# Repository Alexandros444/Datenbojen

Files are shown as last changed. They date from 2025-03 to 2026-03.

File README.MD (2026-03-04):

# Datenbojen
In diesem Projekt wird die Umsetzung einer autonomen Datenerfassungsplattform dokumentiert.

## Bachelorarbeit
Genaueres zu dem Projekt kann in der Bachelorarbeit von Alexander Mohr nachgelesen werden.
[Bachelorarbeit](docs/Datenbojen_Bachelor_Arbeit.pdf)

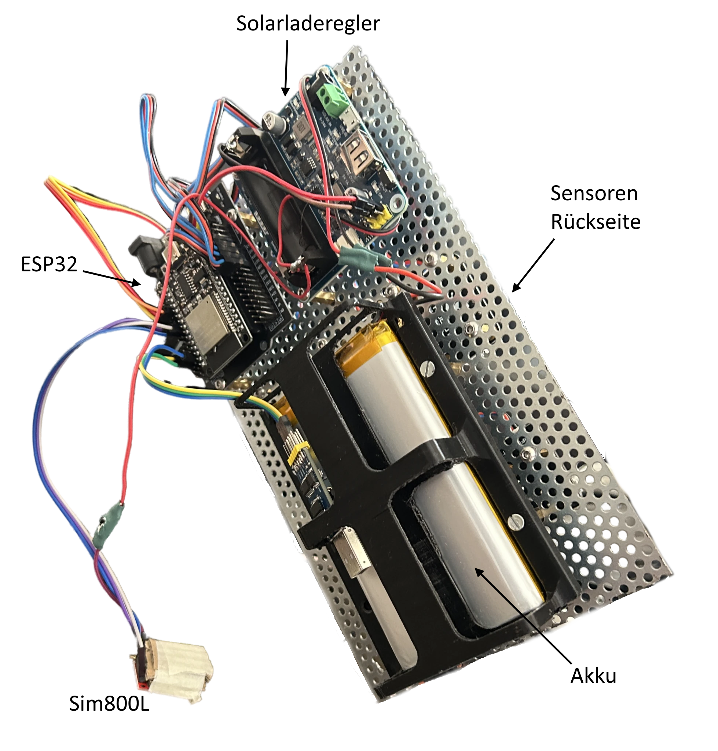
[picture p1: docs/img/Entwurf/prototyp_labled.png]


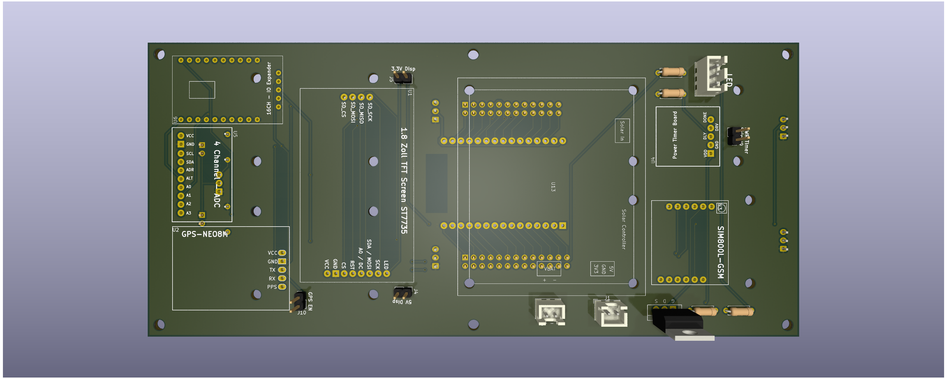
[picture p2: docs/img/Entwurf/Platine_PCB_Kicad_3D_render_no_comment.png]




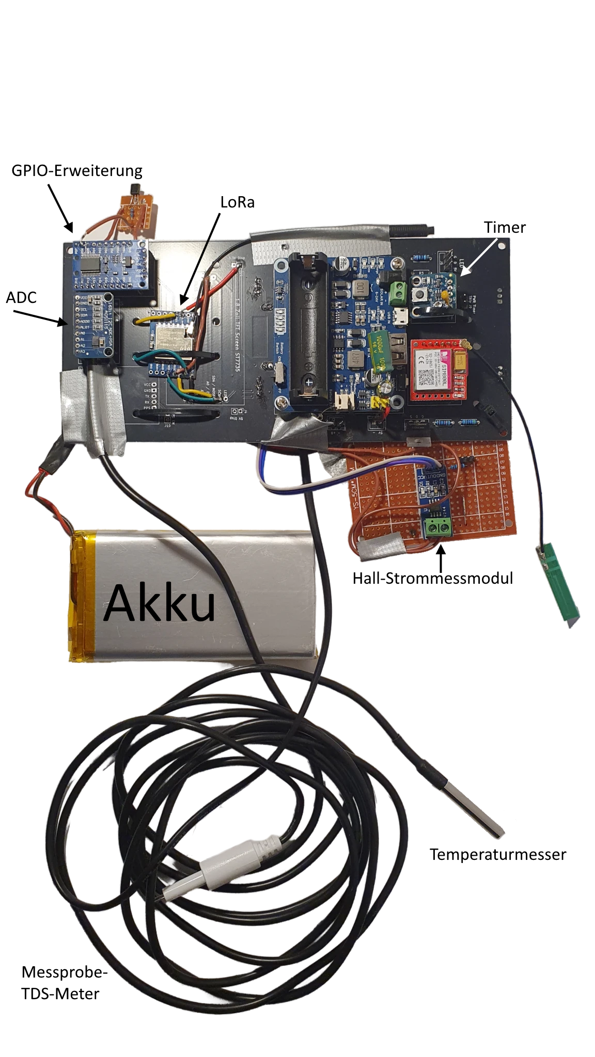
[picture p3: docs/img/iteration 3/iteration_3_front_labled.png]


## Ausstellung
Ein Prototyp des Projekts wurde im Berliner Humboldt Forum ausgestellt.
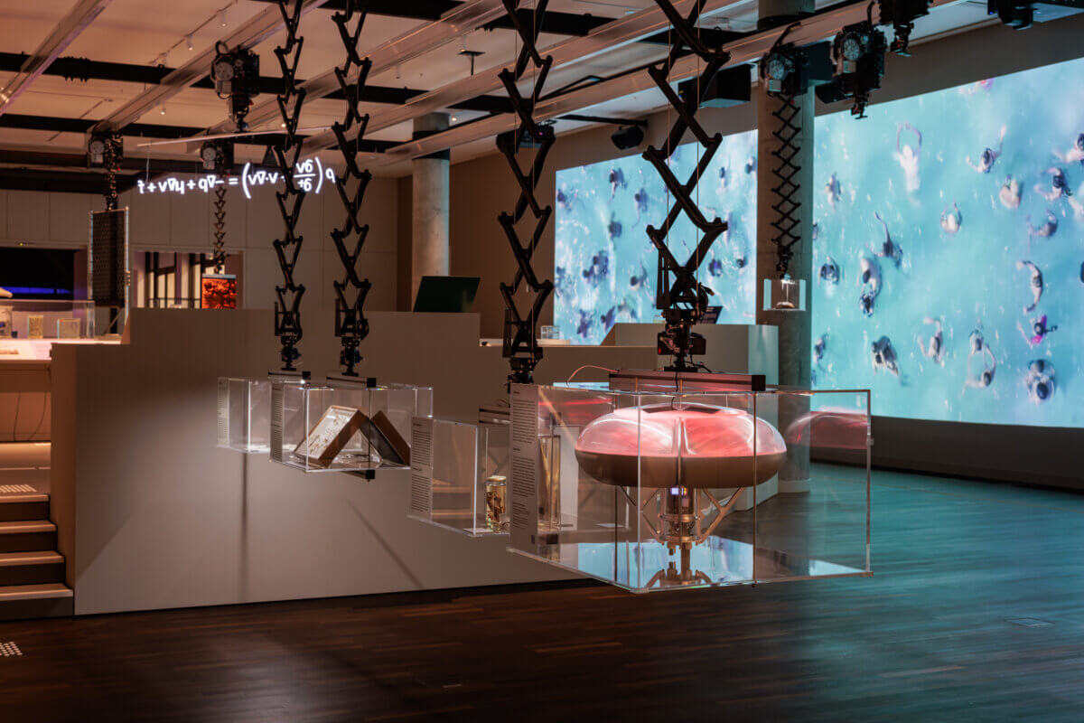
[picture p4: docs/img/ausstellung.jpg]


## Rückfragen
- Email an a.mohr@campus.tu-berlin.de

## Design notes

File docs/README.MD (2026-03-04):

## Bachelorarbeit
[Datenbojen](Datenbojen_Bachelor_Arbeit.pdf)

## Sim-800L
- Dokumentation in [Sim800L_Manual](SIM800%20Series%20AT%20Command%20Manual%20V1.10-1.pdf)
- Kurzfassung in [Docx](AT_Commands.docx)

## Systementwurf
- Flowcharts zur Systemfunktion

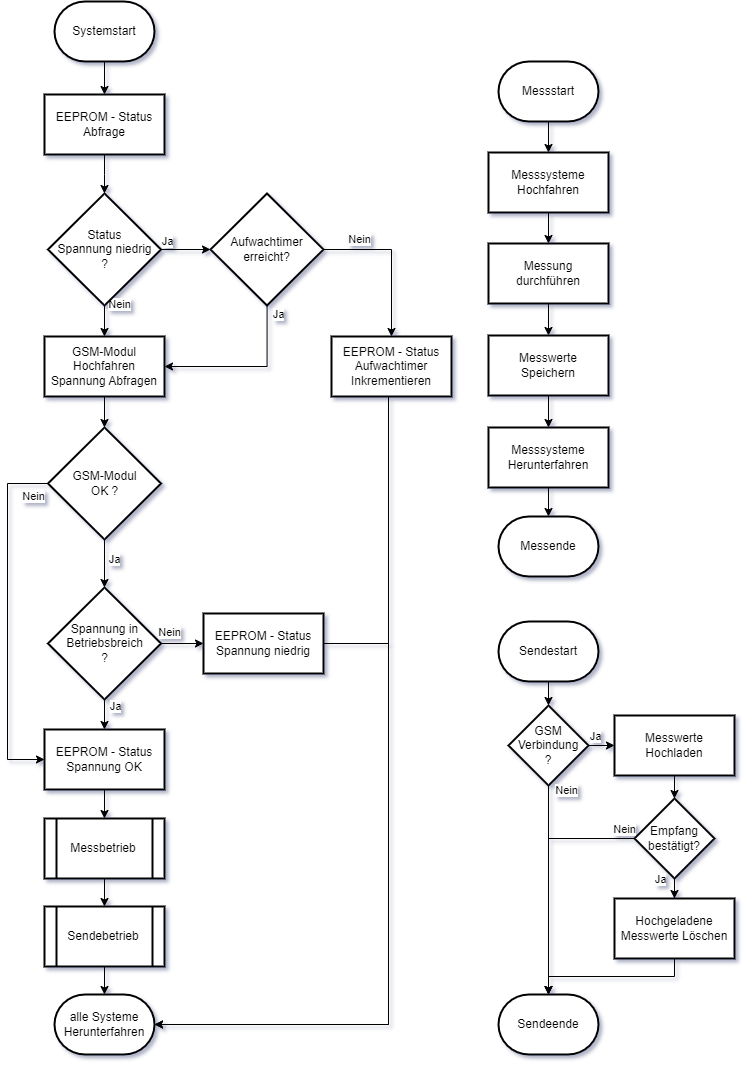
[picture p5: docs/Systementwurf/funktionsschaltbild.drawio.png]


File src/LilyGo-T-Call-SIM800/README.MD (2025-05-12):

<h1 align = "center">🌟LilyGo T-Call SIM800 Series🌟</h1>

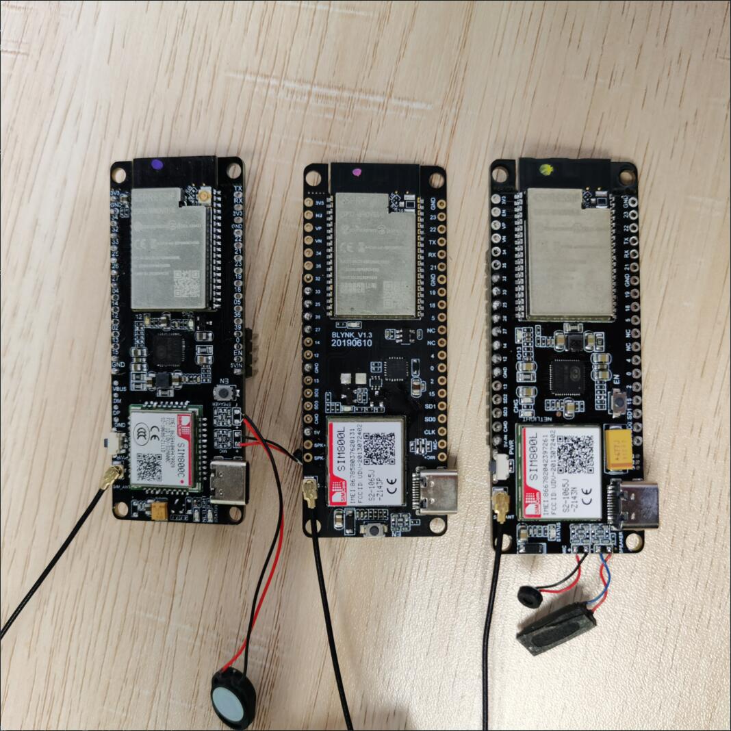
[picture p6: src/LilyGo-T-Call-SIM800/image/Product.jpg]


<h2 align = "left">Product 📷:</h2>

| Examples | Product  Link | Schematic |
| :---: | :---: | :---: |
| [SIM800L IP5306 20200811](./doc/SIM800L_IP5306.MD) | [Product link](https://lilygo.cc/products/t-call-v1-4?variant=42868250869941) | [Schematic](./schematic/LilyGo-SIM800L-IP5306-20200811.pdf) |

## Datasheet

- [SIM800 AT Command](./datasheet/sim800_series_at_command_manual_v1.01.pdf)
- [SIM800 Hardware Design](./datasheet/SIM800_Hardware%20Design_V1.08.pdf)
- [AXP192](http://www.x-powers.com/en.php/Info/product_detail/article_id/29)
- [IP5306](./datasheet/IP5306%20REG%20V1.4.pdf)

## PlatformIO Quick Start

1. Install [Visual Studio Code](https://code.visualstudio.com/) and [Python](https://www.python.org/)
2. Search for the `PlatformIO` plugin in the `VisualStudioCode` extension and install it.
3. After the installation is complete, you need to restart `VisualStudioCode`
4. After restarting `VisualStudioCode`, select `File` in the upper left corner of `VisualStudioCode` -> `Open Folder` -> select the `LilyGo-T-Call-SIM800` directory
5. Wait for the installation of third-party dependent libraries to complete
6. Click on the `platformio.ini` file, and in the `platformio` column
7. Uncomment one of the lines `src_dir = xxxx` to make sure only one line works
8. Click the (✔) symbol in the lower left corner to compile
9. Connect the board to the computer USB
10. Click (→) to upload firmware
11. Click (plug symbol) to monitor serial output
12. If it cannot be written, or the USB device keeps flashing, please check the **FAQ** below

## Arduino IDE Manual installation

1. Install [Arduino IDE](https://www.arduino.cc/en/software)
2. Install [Arduino ESP32 V2.0.5 or later or latest](https://docs.espressif.com/projects/arduino-esp32/en/latest/)
3. Download `LilyGo-T-Call-SIM800` , move to Arduino library folder (e.g. C:\Users\YourName\Documents\Arduino\libraries)
4. Copy all folders in [lib folder](./lib/) to Arduino library folder (e.g. C:\Users\YourName\Documents\Arduino\libraries)
5. Open ArduinoIDE ,`Tools` , Make your selection according to the table below
   | Arduino IDE Setting                  | Value                             |
   | ------------------------------------ | --------------------------------- |
   | Board                                | **ESP32 Dev Module**            |
   | Port                                 | Your port                         |
   | USB CDC On Boot                      | Enable                            |
   | CPU Frequency                        | 240MHz (WiFi/BT)                      |
   | Core Debug Level                     | None                              |
   | Erase All Flash Before Sketch Upload | Disable                           |
   | Events Run On                        | Core1                             |
   | Flash Mode                           | QIO 80MHZ                         |
   | Flash Size                           | **4MB (32Mb)**                   |
   | Arduino Runs On                      | Core1                             |
   | Partition Scheme                     | **Default 4MB with spiffs (1.2MB APP/1.5MB SPIFFS)** |
   | PSRAM                                | **QSPI PSRAM**                     |
   | Upload Mode                          | **UART0/Hardware CDC**            |
   | Upload Speed                         | 921600                            |

   - The options in bold are required, others are selected according to actual conditions.

6. `File` -> `Examples` -> `LilyGo-T-Call-SIM800` -> `Arduino Examples`
7. Select `Port`
8. Click `upload` , Wait for compilation and writing to complete

## FAQ

### 1. If you are unable to download, please try the following steps, if it still does not work, please contact customer service

1. Open the serial monitor
2. Short IO0 to GND
3. Press the RESET button on the board, if the serial port communication is normal, then you should see

    ```bash
    ets Jun 8 2016 00:22:57

    rst:0x1 (POWERON_RESET),boot:0x3 (DOWNLOAD_BOOT(UART0/UART1/SDIO_REI_REO_V2))
    waiting for download
    ```

4. If you can see the above message, it means that the communication is normal, then all you need is to let it enter the waiting download mode, then you can click upload, usually it can solve the problem of not being able to download automatically

### 2. About the 5V power pin description on the board

   - For IP5306 power supply, the 5V power pin connected to the USB board is the output, and the voltage is boosted by IP5306 power supply chip.  According to the manual, its maximum output current is 2.4a.  Do not connect USB, can 5V input.
   - When using AXP192 power supply, the 5V power pin on the board is the input, and it is connected with USB 5V+. There is no other power output on the board except for the 3.3V output.

### 3. Didn’t connect to the Internet for a long time, or just turned off suddenly?

   - It may be due to insufficient USB power supply current, please connect a lithium battery to the board, then plug in the USB and test again.

### 4. Why doesn’t the board turn on when the lithium battery is connected?

   - If you use the **IP5306** version and use a lithium battery to supply power, you must press the reset button to turn on the board. 
   - If you use the **AXP192** power management chip, you need to press and hold the PWR button for 2 seconds to turn on the power supply. By default, the AXP192 will be powered on when the battery is inserted. 

### 5. About SIM800X built-in firmware update

   - SIM800 built-in firmware update tool Because SIMCOM has not adapted and updated the new system for a long time, it is not necessarily available to upgrade the built-in firmware tool. Most users are stuck waiting for download. Please be informed
   - [How to update firmware](doc/How%20to%20update%20firmware.md)

### 6. LED indicators

- Blue LED, controlled by GPIO13
- Red LED, network status light

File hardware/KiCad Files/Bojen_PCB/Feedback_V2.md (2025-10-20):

## IO Expander
- [x] Silkscreen missing
- [x] Holes to small
- Weitere Pins zugänglich machen

## Sim Module
- [x] Silkscreen missing
- [ ] Mosfet DOES NOT WORK, Wenn ESP aus, wird gpio auf GND gezogen,  ~1.1V gemessen Spannungsteiler innenwiderstand berechnen? Auf Nicht inv. wechseln
- RESET PIN wird gebraucht

## TMP Sensor
- [x] Beschriftung Falsch "- + D" -> "- D +"

## GSM Module
- [x] Mehr Pufferkondensatoren
    - 100u, 10u
- [x] PWR Mosfet Skip
- [x] RST Pin auf GPIO für Hard Reset

## Power
- [x] Puffer Kondensatoren
    - 100u, 10u

## Kosten
- JST - XH - 5€
- Pin Headers - 2€
- DS18B20

# ESP
- [x] GPIO Label Silkscreen TODO / Label Pin Header
- [x] USB-C kann man nicht einstecken wenn Sensoren verbaut. ggf. (Sensoren Tiefer legen) oder esp mehr nach unten
- [o] USB verbindung rausführen, aber USB - TTL benötigt (not worth it)

# Mount Holes
- Mehr Clearence
- [x] Besonders bei den ESP-GPIO Pins zu dem mount vom Waveshare solar board

# Solar Modul
- Power reroute backup, Battery voltage for development

# Sensoren
- [x] Sensoren Distanz zu Board anschlüssen sind zu kurz für Steckverbindungen
- ADC Pins beschriften Bei Sensoren A0-A3

# Board
- Alle Pins rausbringen (oben Vcc anschlüsse etc.)
- [x] Alle GPIO Pin header für extension board
- GPIO Default connected pins (everywhere solder work minimizing)

# LED
- Braucht kein Widerstand für Data weil, ESP 3.3V

# Timer
- [x] Buffer Capacitor

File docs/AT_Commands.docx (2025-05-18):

Network Registration:

AT+CREG

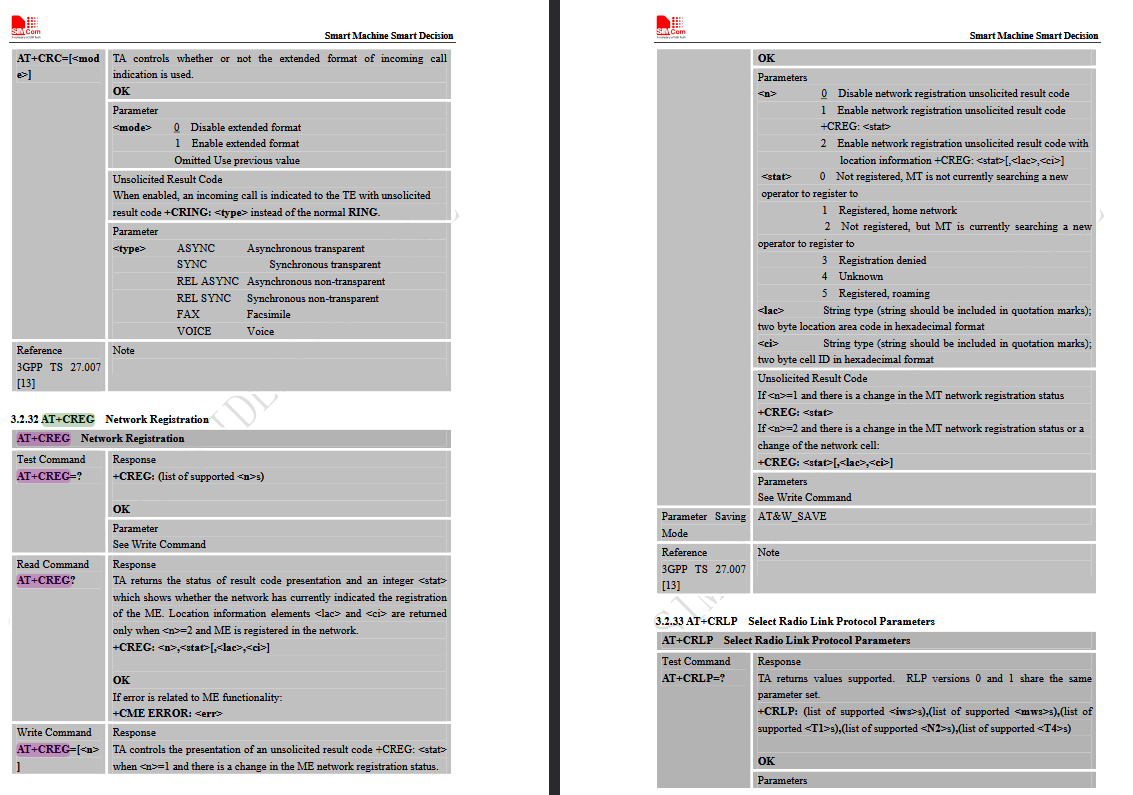
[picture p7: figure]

AT+CGREG

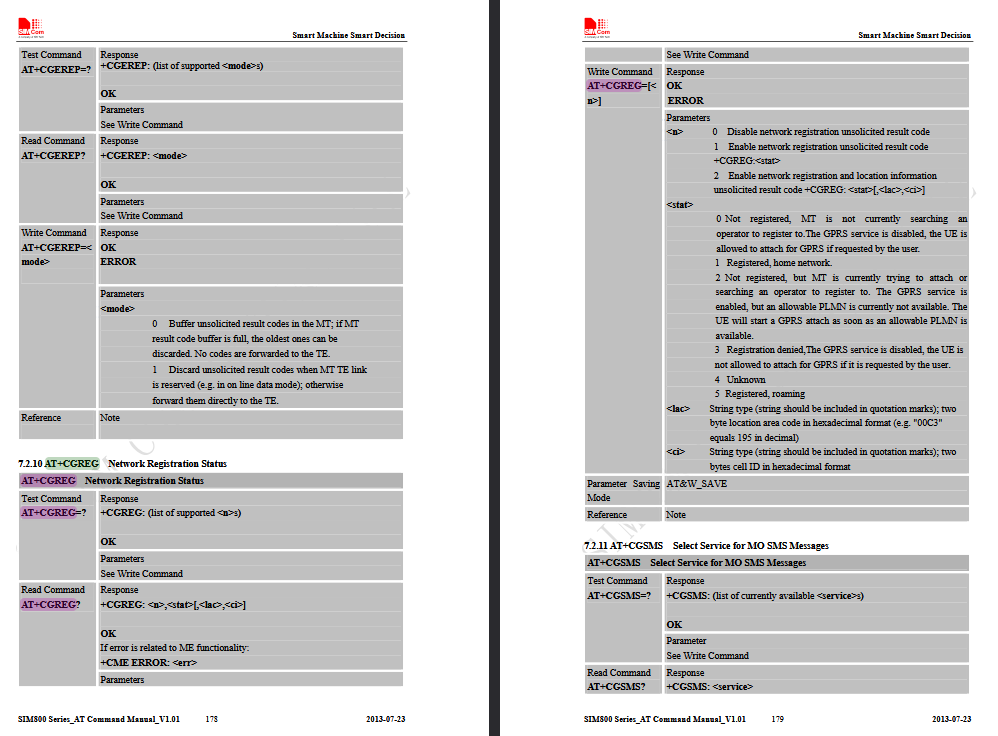
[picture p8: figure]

Settings Bearer IP Application

AT+SAPBR

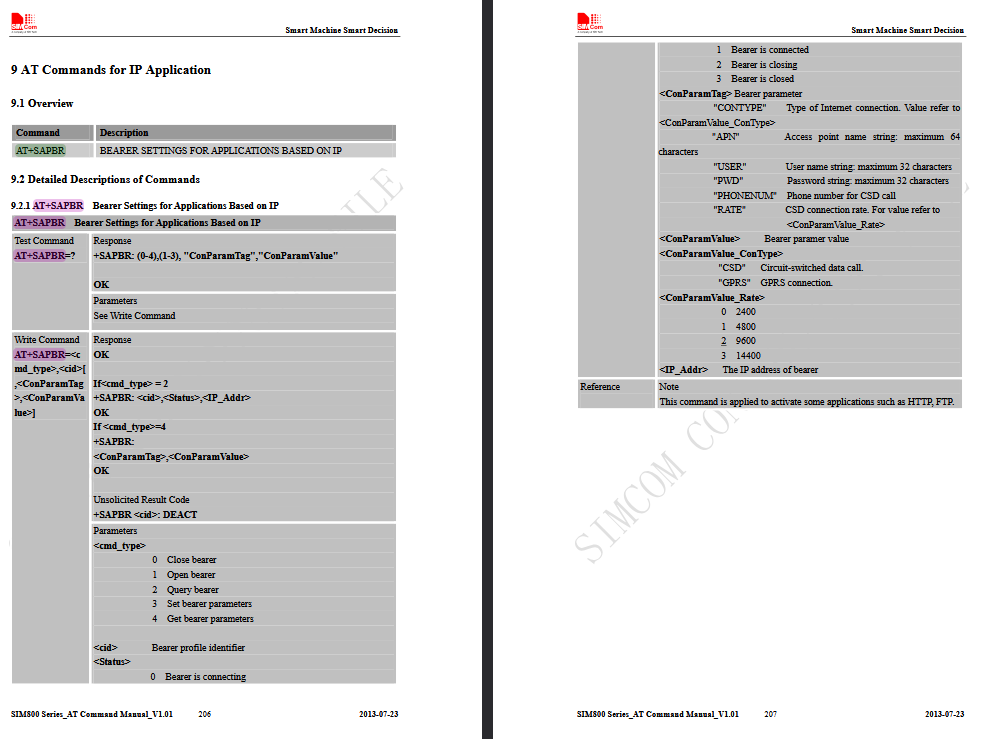
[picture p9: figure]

AT+HTTPINIT

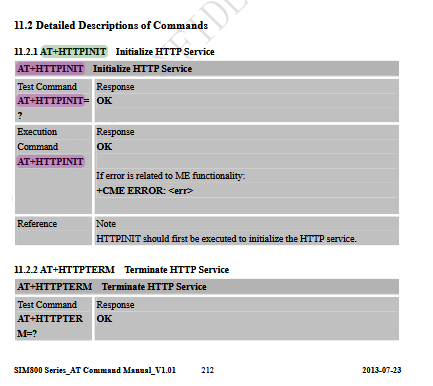
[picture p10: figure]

AT+HTTPPARA

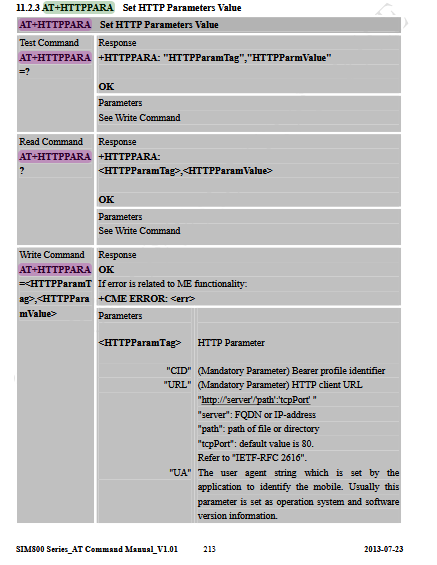
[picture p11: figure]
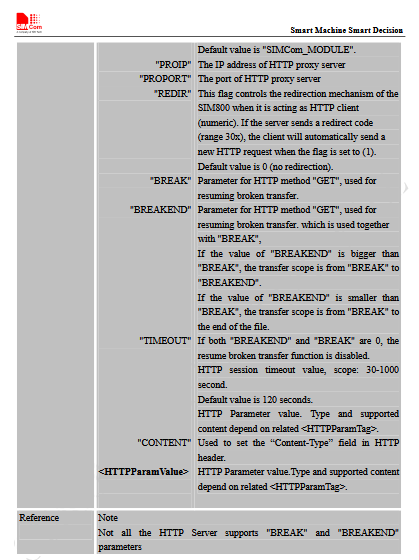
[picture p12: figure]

AT+HTTPDATA

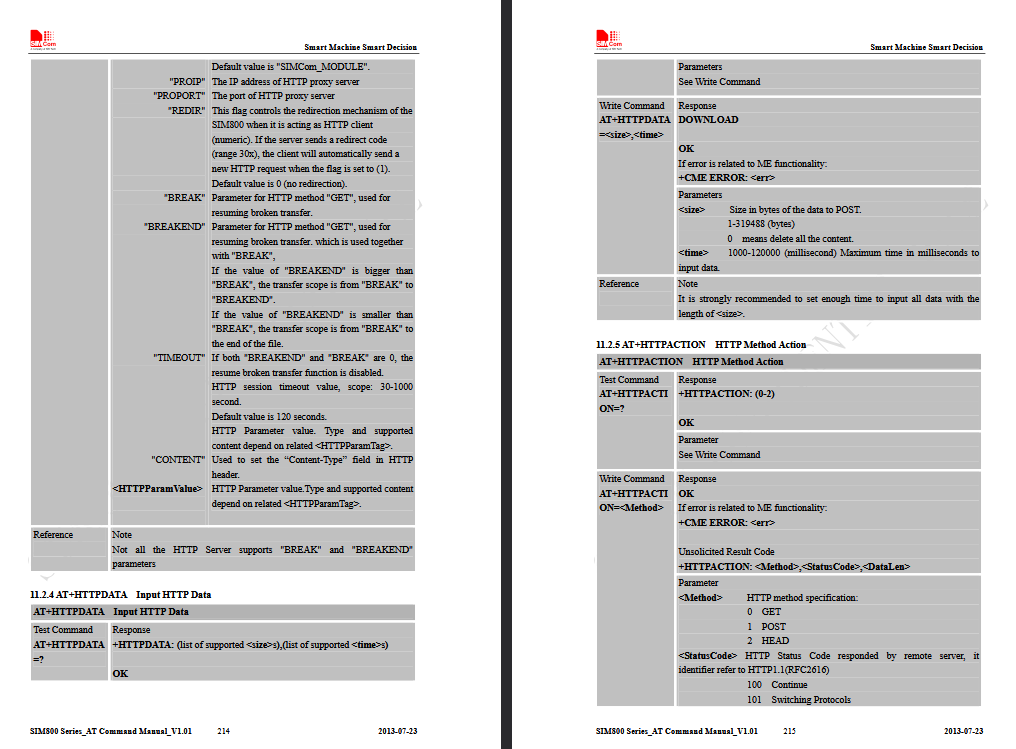
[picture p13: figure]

AT+HTTPREAD

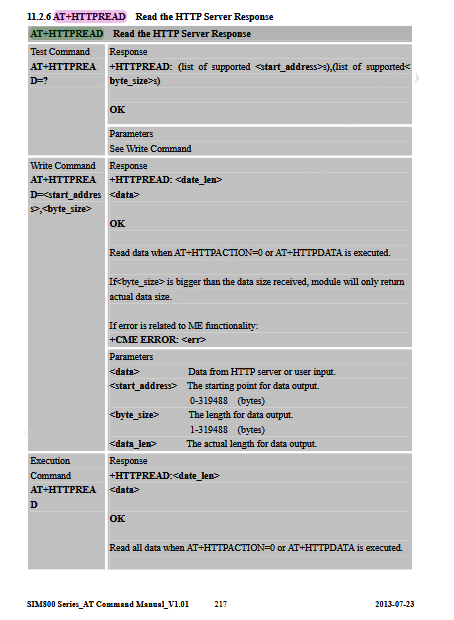
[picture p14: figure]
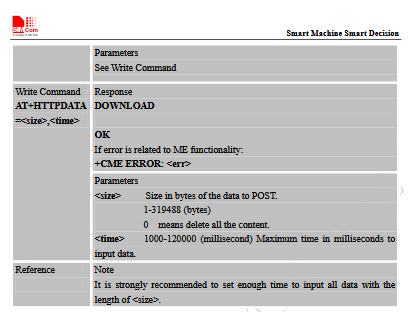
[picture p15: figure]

AT+HTTPACTION

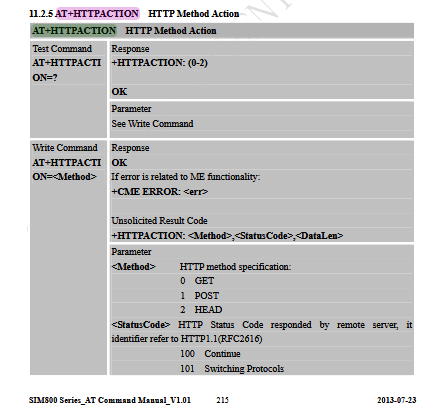
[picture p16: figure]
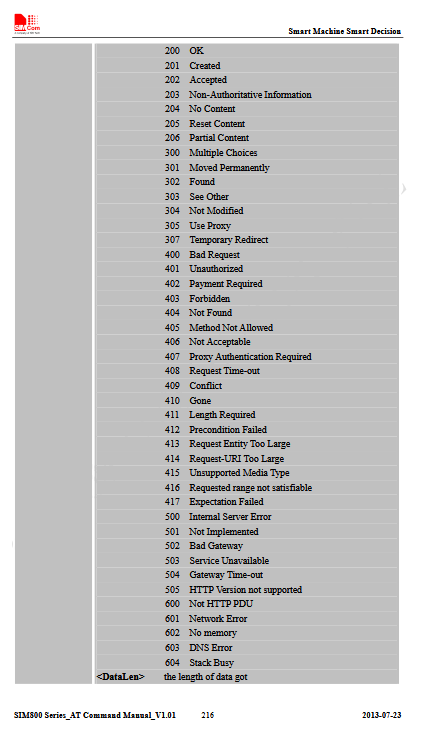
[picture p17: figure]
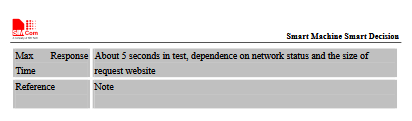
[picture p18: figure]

AT+HTTPTERM

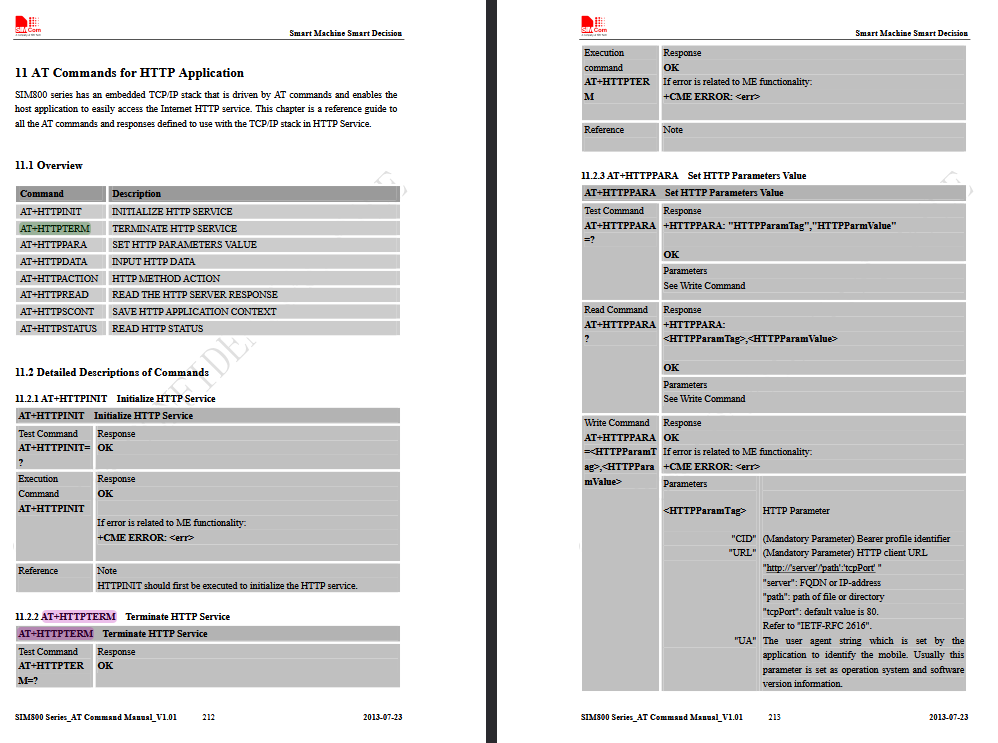
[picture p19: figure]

Select SMS Message Format

AT+CMGF

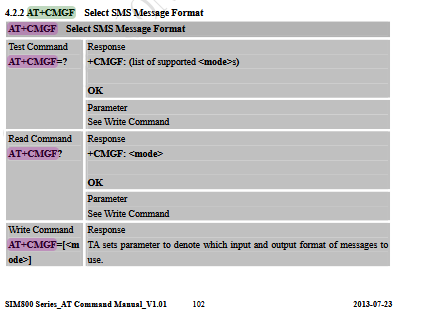
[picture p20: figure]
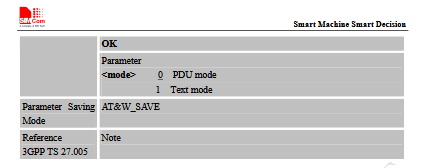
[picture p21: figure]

Send SMS

AT+CMGS

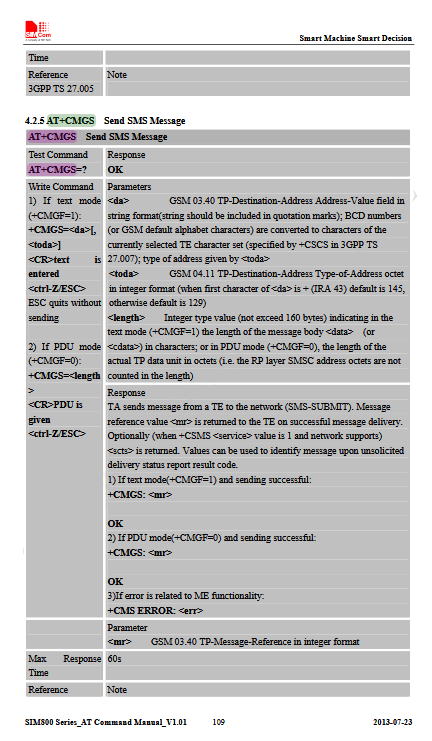
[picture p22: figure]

Battery: AT+CBC
Charging, Percent, MilliVolts

# Network:

Network Registration Status:

AT+CREG? (AT+CGREG (2G oderso))

+CREG 0,1-> (Sucht nicht), (Home Network)

Bearer Info

AT+SAPBR=2,1 (2 get info, 1. Bearer)

+SAPBR: 1,3,"0.0.0.0" (1. Bearer, 3 Closed)

AT+SAPBR=1,1 (1 öffnen, 1. Bearer)

+SAPBR: 1,1,"10.42.71.191" (1. Bearer, 1 Offen, ip)

AT+SAPBR=4,1 (2 get AP info, 1. Bearer)

+SAPBR:

CONTYPE: GPRS

APN:

PHONENUM:

USER:

PWD:

RATE: 2

HTTP

AT+HTTPINIT

AT+HTTPPARA="URL","http://google.com" (Setzt URL)

AT+HTTPPARA="CID",1 (Setzt 1. Bearer)

AT+HTTPACTION=0 (0 – HTTP Get)

+HTTPACTION: 0,301,219 (301 moved, 219 – Data Len)

+HTTPACTION: 0,200,18618 (200 OK, 18618 – Data Len

AT+HTTPREAD

<!Doctype HTML> etc…. </html>

AT+HTTPTERM (Beendet HTTP Mode)

AT+SAPBR=0,1 (0 Close, 1. Bearer)

# POST DATA

Wie in Network:

AT+HTTPDATA=<DataLen>,<WaitForInputTimeMs>

AT+HTTPDATA=10,10000
DOWNLOAD (Von Sim geschickt)

TEST (Post Data)

AT+HTTPACTION=1 (1-Post)
+HTTPACTION: 1,603,0 (1-Post, 603 Fehlercode DNS (HTTPS geht nicht), 0-Length)
+HTTPACTION: 1,200,360 (1, 200 OK, 360 – Length Data)

AT+HTTPREAD

{

"args": {},

"data": "TEST\nTEST\n",

"files": {},

"form": {},

"headers": {

"Accept": "*/*",

"Content-Length": "10",

"Host": "httpbin.org",

"User-Agent": "SIMCOM_MODULE",

"X-Amzn-Trace-Id": "Root=1-67b5fc86-2c27111747bdae5175fc23dd"

},

"json": null,

"origin": "80.187.87.72",

"url": "http://httpbin.org/post"

}

OK

AT+HTTPTERM

# SMS:

AT+CMGF=? (Get List of Supported Formats)
+CMGF: (0,1) (0 pdu, 1 text)

AT+CMGF? (Get active Text Mode)
+CMGF: 0 (0 PDU Mode) (Binary Bit Stream vllt interessant)

AT+CMGF=1 (Set Text Mode)

AT+CMGS="+4915739119874" (Receiver Number)

Message

CTRL+Z (Send with Code: 0x1a)

+CMGS: 6 (6 <da> ? Kein Ahnung, fortlaufende Nummer irgendwie)

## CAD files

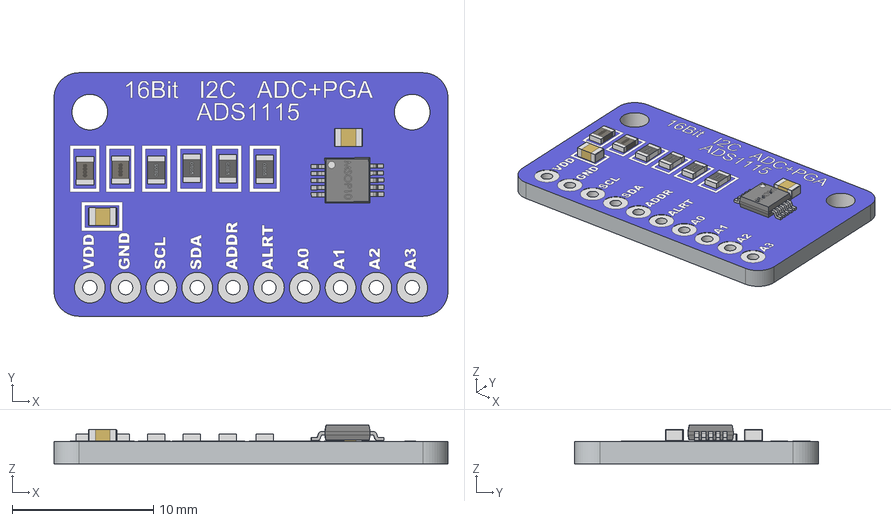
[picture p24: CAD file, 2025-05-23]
hardware/KiCad Files/KiCad_IC_Footprint/16Bit I2C ADC+PGA - ADS1115.stp
27.9 x 17.3 x 2.74 mm
ADS1115
0805 Capacitor x 2
0805 Inductor x 2
0805 Resistor x 4
MSOP10

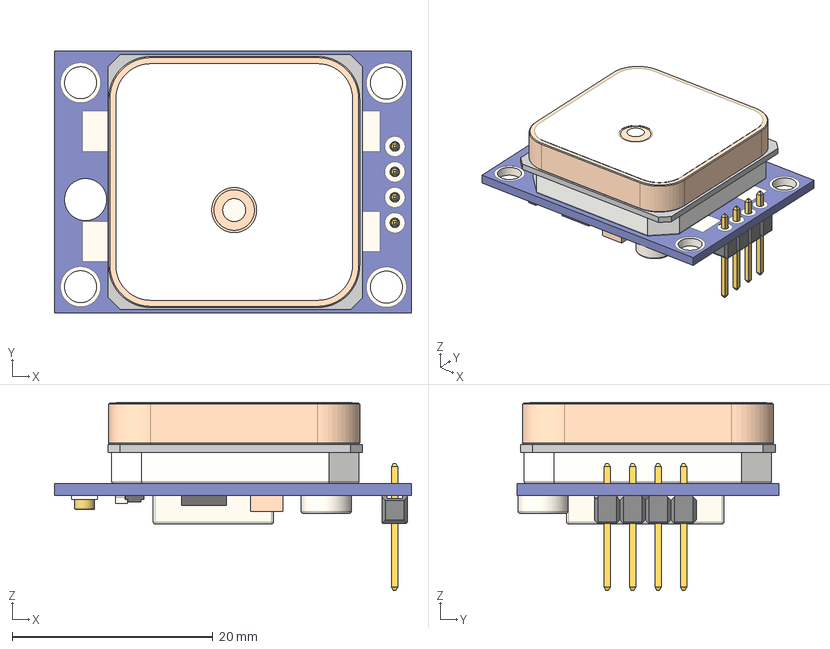
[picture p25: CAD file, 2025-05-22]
hardware/KiCad Files/KiCad_IC_Footprint/GY-NEO6MV2-withAnt v7.step
35.6 x 26.1 x 19.0 mm
Pin Header 1x4 TH Pitch 2.54mm

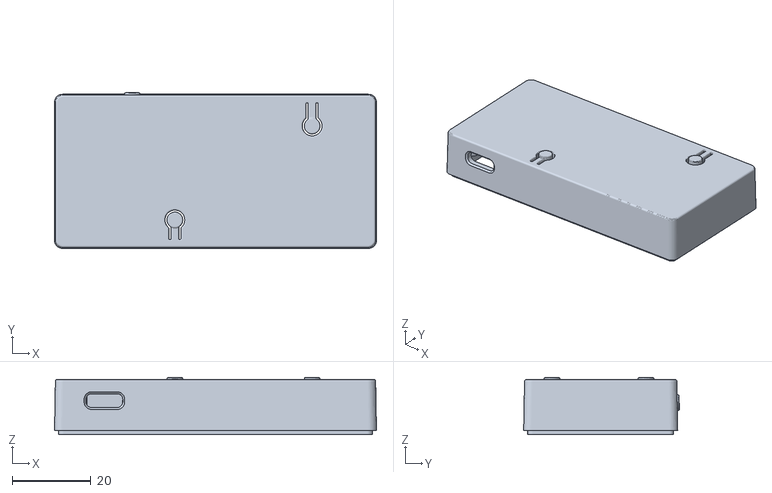
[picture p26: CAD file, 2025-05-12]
src/LilyGo-T-Call-SIM800/3D_File/2.stl
81.6 x 39.5 x 14.5

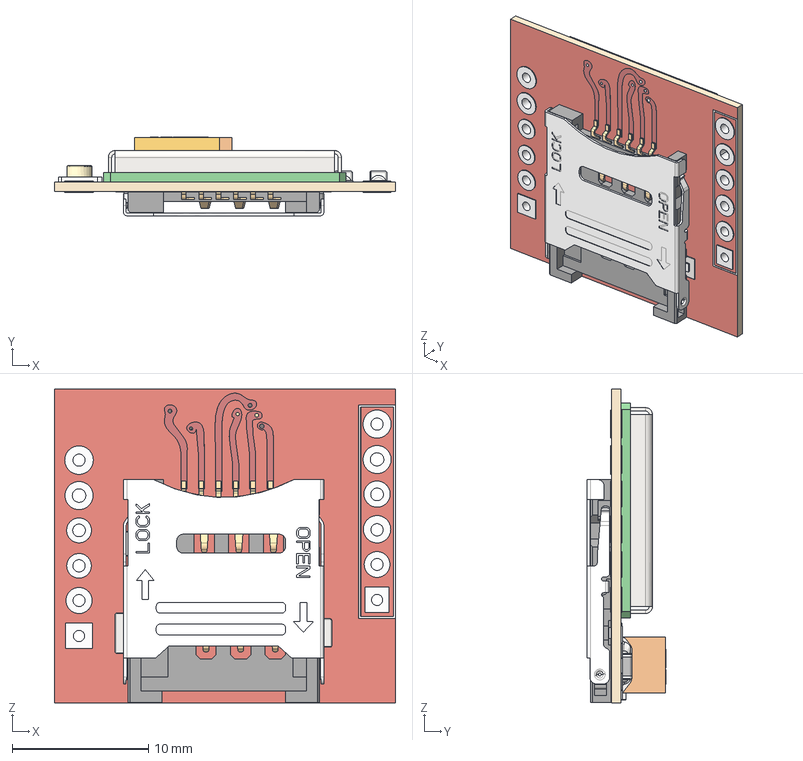
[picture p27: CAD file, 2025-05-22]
hardware/KiCad Files/KiCad_IC_Footprint/SIM800L v10.step
25.0 x 5.77 x 23.0 mm
PCB
Cage
CH03-HB

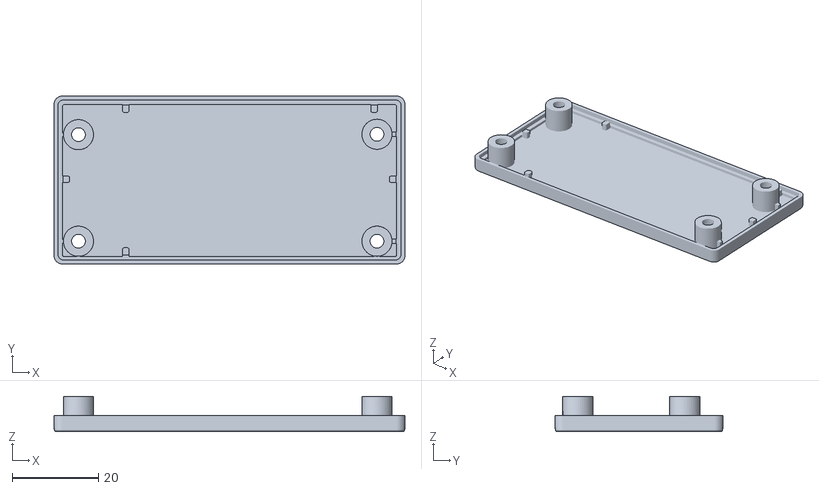
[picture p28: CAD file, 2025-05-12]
src/LilyGo-T-Call-SIM800/3D_File/1.stl
81.6 x 39.0 x 8.20

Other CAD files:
src/LilyGo-T-Call-SIM800/3D_File/T-Call-V1.4.dwg

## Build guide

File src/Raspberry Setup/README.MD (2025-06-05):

# Raspberry Setup
## General
- Usr: riversync
- pwd: 55555spreeart$
- ssh riversync@9.tcp.eu.ngrok.io -p 25669
- [Backup] (https://raspberrystreet.com/learn/how-to-backup-raspberrypi-sdcard)

## Motion - Kamerastream auf Webserver
- [Tutorial](https://www.instructables.com/How-to-Make-Raspberry-Pi-Webcam-Server-and-Stream-/)
- Deamon Mode off! Wegen Systemd
- Current Locations:
    - `/etc/motion/motion.conf`
    - `/var/log/motion/motion.log`
    - `/var/lib/motion/`
- Camera Webstream 8080
- Camera Config 8081

## Ngrok - Erreichbarkeit vom Internet
- [Tutorial auch Nginx](https://medium.com/@herman.daniel/raspberry-pi-secured-webcam-streaming-with-motion-nginx-and-ngrok-eb31c46ecedd)
- Config wo? `ngrok config check`
- Current Locations:
    - `/home/riversync/.config/ngrok/ngrok.yml`
- Website: [https://partly-suitable-parrot.ngrok-free.app/](https://partly-suitable-parrot.ngrok-free.app/)
- SSH login über TCP [Ngrok](https://dashboard.ngrok.com/endpoints?sortBy=updatedAt&orderBy=desc)
- Forward tcp an 22 (SSH)
- Forwarded jetzt http an 80 also nginx
- old
    - Forwarded http an localhost 8000 (icecast)

## Icecast - Webserver (Audio)
- Relay Camera Webserver
- Current Location:
    - `/etc/icecast2/icecast.xml`
- Usr: admin
- pwd: 55555
- Relay 8000 -> 8081 Cam Stream
    - Relay in icecast.xml auf 8081 port von Camserver
- Host Webserver on 8000

## Darkice - Audio Stream
- [Tutorial auch Icecast](https://www.hackster.io/Shilleh/stream-audio-from-raspberry-pi-to-local-computer-02c7f0)
- Current Location:
    - `/etc/darkice.cfg`
- Automatic Execution rc-local service:
    - `/etc/rc.local`
- Send Data to Icecast in config

## MJPG-Streamer
- [Tutorial](https://github.com/TechsPassion/RaspberryPi/blob/main/Webcam_Streaming.md)
- [Github](https://github.com/jacksonliam/mjpg-streamer/tree/master)
- Location mjpg_config
    - `/etc/default/mjpg_streamer`
- Location mjpg_stream
    - `/usr/local/bin/mjpg-streamer/mjpg-streamer-experimental/`
    - scripts für die Service Datei (jetzt unter `/etc/systemd/system/mjpg-streamer.service`)
    - www für Webserver
- System Service hosted Website
- auf port 8888

## Nginx - Lokaler Webserver
- Current Location: 
    - `/etc/nginx/sites-available/node`
- Login No in Use 
    - Usr: pi
    - pwd: raspberry
- Linkt von http (80) auf 8888 bzw 8888?actioon=stream für später wenn man die config nicht mehr von außen erreichen soll

## Zrok - Network Tunnel

- Autostart in:
    - `/etc/rc.local`
- Service einrichten: `zrok enable <AuthToken>
- Webserver Weiterleiten: `zrok share public 8000` (icecast2)
    - Share Reservieren: `zrok reserve public 80 --unique-name "riversync"`
    - Reservierte Share Starten: `zrok share reserved "riversync"`
- SSH Weiterleiten: `zrok share private --backend-mode tcpTunnel 127.0.0.1:22`
    - Client: `zrok access private <Private Token new generated>` (Lokaler Server verbindet sich mit Tunnel, hosted on 9191)
    - Cleint: `ssh riversync@127.0.0.1 -p 9191` (SSH into Lokalen Server - Tunnel - Riversync)

## Control.sh
- Easy managable config
- has to be updated for the mjpg-server

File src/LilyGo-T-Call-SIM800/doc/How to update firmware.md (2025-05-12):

# Step

```bash
SIM800 built-in firmware update tool Because SIMCOM has not adapted and updated the new system for a long time, it is not necessarily available to upgrade the built-in firmware tool. Most users are stuck waiting for download. Please be informed

```

## 1. First, you need to update the ESP32's built-in firmware, open the `UpdateFirmware` example, compile and burn it into the board. 

## 2. Unzip `SIM800_Series_download_Tools_Customer_v1.23.rar` 

## 3. Open `Flash_tool.exe`

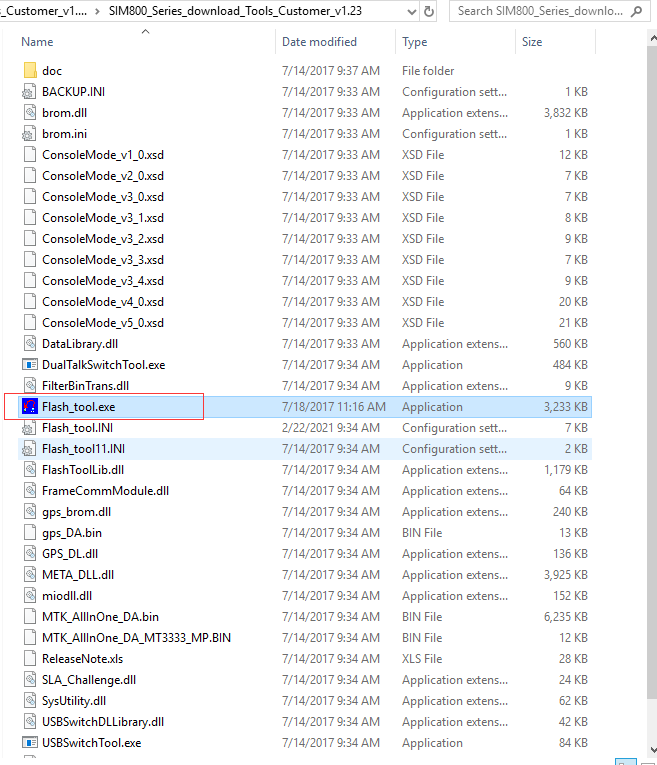
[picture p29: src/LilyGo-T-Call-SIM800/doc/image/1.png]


### 4. Select the relative firmware and port according to the diagram 

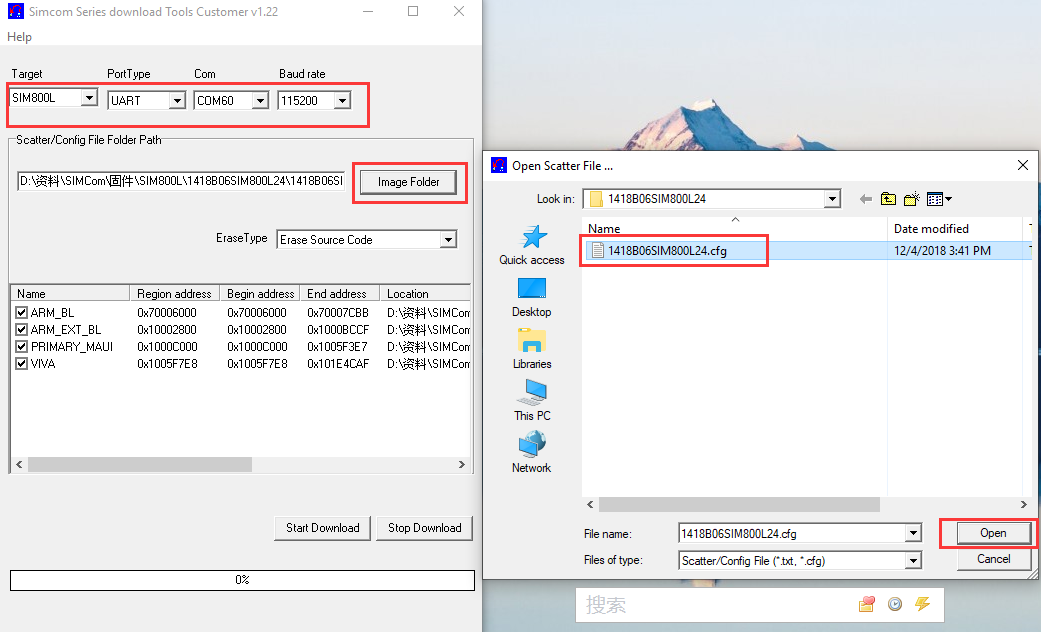
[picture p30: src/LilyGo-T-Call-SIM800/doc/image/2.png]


### 5. Wait for the board indicator to light up, then click the `Start Download` button, and wait for it to finish 

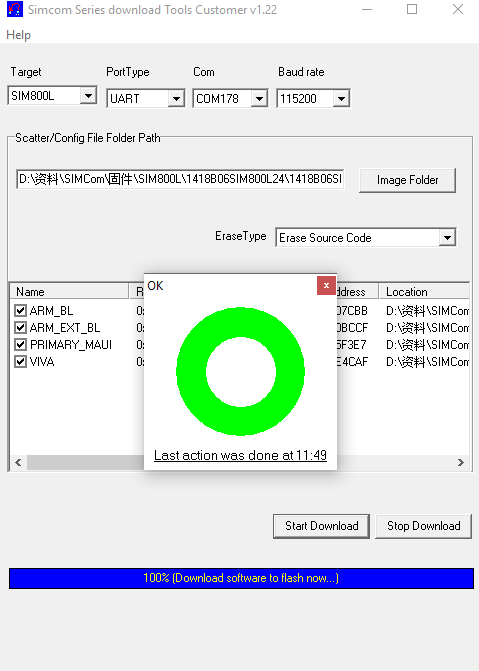
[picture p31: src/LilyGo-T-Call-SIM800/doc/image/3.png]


# Firmware Link

- [Flash Tools](https://drive.google.com/file/d/10vdCpkkIqNJgv__gS-UiqMGG8SjLcOAY/view?usp=sharing)
- [SIM800L 1309B10SIM800L16](https://drive.google.com/file/d/113vc3ZM0Q1w6rW1ycc6x3apyU7B4XSm6/view?usp=sharing)
- [SIM800C 1309B12SIM800H32](https://drive.google.com/file/d/116Ddasj-t7ceH3Ql5xfgSKEsQudqG6xC/view?usp=sharing)

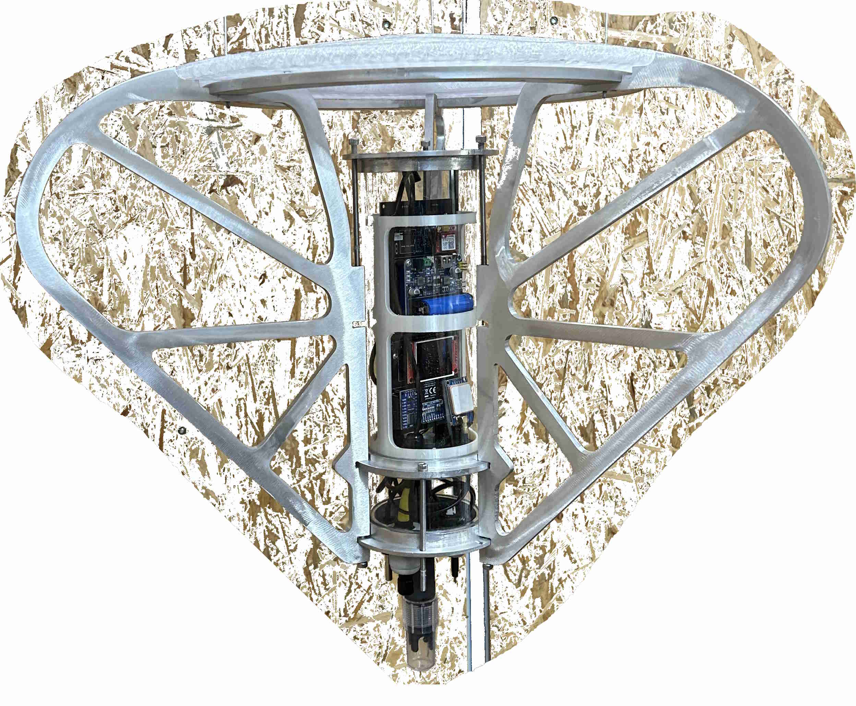
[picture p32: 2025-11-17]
docs/img/Entwurf/boje_aufbau.jpg

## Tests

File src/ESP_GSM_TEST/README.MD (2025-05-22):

# Documentation Lilygo ESP32
- [LILYGO Shop Site mit Pinout Referenz](https://lilygo.cc/products/t-call-v1-4)

- User_Setup.h muss nach pio libdeps TFT_eSPI kopiert werden

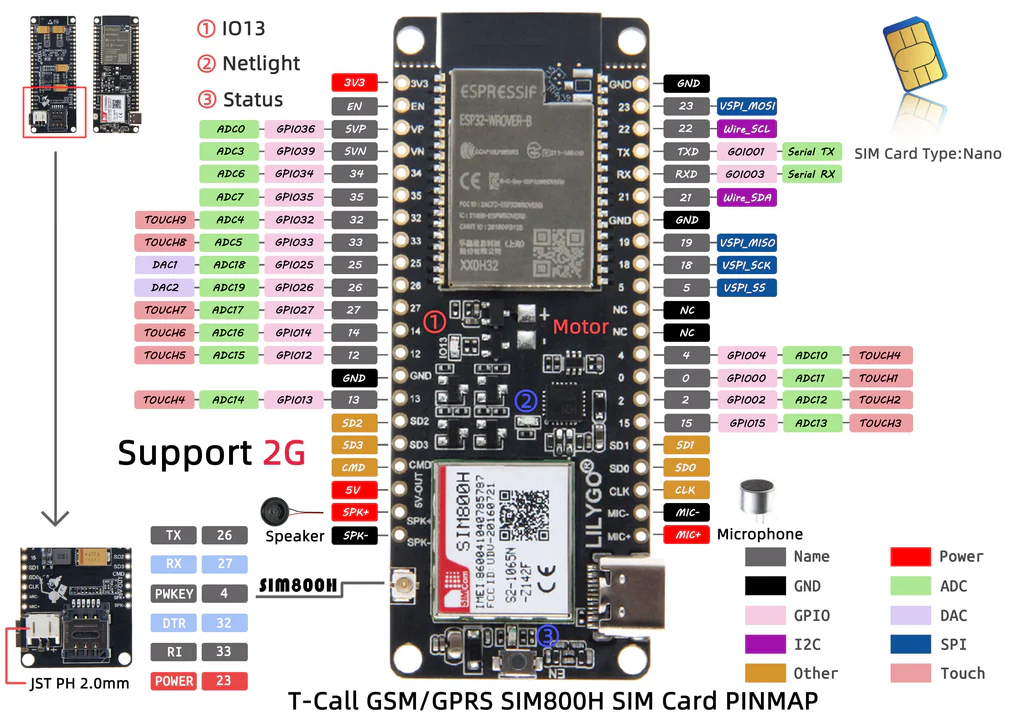
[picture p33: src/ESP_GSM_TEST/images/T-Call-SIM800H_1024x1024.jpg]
Pinout Lillygo Board


- ADC wird gebraucht:
[ADS1115 Tutorial](https://learn.adafruit.com/adafruit-4-channel-adc-breakouts/arduino-code#construction-and-initialization-4-2)

- GPIO Expansion wird gebraucht [Shop]()

---
<br>
<br>
<br>

# Pin Belegung ESP32 Wroom
ESP32 Wroom Pinout

- 

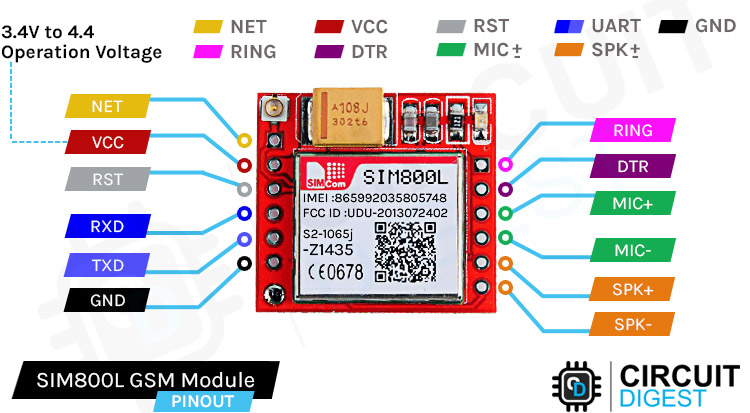
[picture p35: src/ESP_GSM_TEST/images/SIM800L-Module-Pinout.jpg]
Sim800L


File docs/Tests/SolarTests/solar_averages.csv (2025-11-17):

Messreihe | Durchschnitt pro Tag [Wh]
Messreihe 1 | 0.89
Messreihe 2 | 2.63
Messreihe 3 | 3.17
Messreihe 4 | 2.54
Gesamtdurchschnitt | 2.31

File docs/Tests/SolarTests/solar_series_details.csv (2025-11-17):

Messreihe | i | Time | Wh | ΔT | ΔWh
Messreihe 1 | 0 | 6:30 | 2.77 | 6:30 | 2.77
Messreihe 1 | 1 | 13:00 | 2.94 | 6:30 | 0.17
Messreihe 1 | 2 | 42:40 | 3.5 | 29:40 | 0.56
Messreihe 1 | 3 | 62:00 | 4.1 | 19:20 | 0.6
Messreihe 1 | 4 | 87:40 | 5 | 25:40 | 0.9
Messreihe 1 | 5 | 106:20 | 6.2 | 18:40 | 1.2
Messreihe 1 | 6 | 144:14 | 6.66 | 37:54 | 0.46
Messreihe 1 | 7 | 169:00 | 7.1 | 24:46 | 0.44
Messreihe 2 | 0 | 8:30 | 2.68 | 8:30 | 2.68
Messreihe 2 | 1 | 17:00 | 2.7 | 8:30 | 0.02
Messreihe 2 | 2 | 34:00 | 5.12 | 17:0 | 2.42
Messreihe 2 | 3 | 71:20 | 9.51 | 37:20 | 4.39
Messreihe 2 | 4 | 81:25 | 10.09 | 10:5 | 0.58
Messreihe 2 | 5 | 91:25 | 12.15 | 10:0 | 2.06
Messreihe 2 | 6 | 137:40 | 15.95 | 46:15 | 3.8
Messreihe 2 | 7 | 148:51 | 16.85 | 11:11 | 0.9
Messreihe 2 | 8 | 184:20 | 21.36 | 35:29 | 4.51
Messreihe 2 | 9 | 199:40 | 23.67 | 15:20 | 2.31
Messreihe 3 | 0 | 9:55 | 0.5 | 9:55 | 0.5
Messreihe 3 | 1 | 50:39 | 3.65 | 40:44 | 3.15
Messreihe 3 | 2 | 80:15 | 6.64 | 29:36 | 2.99
Messreihe 3 | 3 | 84:36 | 6.7 | 4:21 | 0.06
Messreihe 3 | 4 | 93:13 | 8.49 | 8:37 | 1.79
Messreihe 3 | 5 | 148:31 | 18.84 | 55:18 | 10.35
Messreihe 3 | 6 | 159:51 | 22.22 | 11:20 | 3.38
Messreihe 4 | 0 | 12:21 | 2.9 | 12:21 | 2.9
Messreihe 4 | 1 | 63:18 | 4.4 | 50:57 | 1.5
Messreihe 4 | 2 | 95:31 | 10.3 | 32:13 | 5.9
Messreihe 4 | 3 | 123:0 | 15.3 | 27:29 | 5.0
Messreihe 4 | 4 | 138:42 | 16.8 | 15:42 | 1.5
Messreihe 4 | 5 | 150:19 | 17.8 | 11:37 | 1.0

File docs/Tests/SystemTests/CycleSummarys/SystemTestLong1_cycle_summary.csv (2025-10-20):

cycle | t_start_s | t_send_s | t_end_s | dur_measure_s | dur_send_s | dur_sleep_s | mean_power_measure_mW | mean_power_send_mW | mean_power_sleep_mW | total_energy_meas_Ws | total_energy_send_Ws | total_energy_sleep_Ws | total_energy_cycle_Ws | cycle_duration_s
1 | 3.8 | 23.8 | 60.6 | 20.0 | 36.8 | 314.4 | 537.0 | 455.6 | 4.3 | 10.7 | 16.8 | 1.3 | 28.9 | 371.2
2 | 375.0 | 395.0 | 434.7 | 20.0 | 39.7 | 244.7 | 543.1 | 454.2 | 4.4 | 10.9 | 18.0 | 1.1 | 30.0 | 304.4
3 | 679.4 | 699.4 | 734.0 | 20.0 | 34.6 | 0.0 | 525.7 | 448.1 | 0.0 | 10.5 | 15.5 | 0.0 | 26.0 | 54.6

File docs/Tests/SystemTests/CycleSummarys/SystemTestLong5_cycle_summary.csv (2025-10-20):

cycle | t_start_s | t_send_s | t_end_s | dur_measure_s | dur_send_s | dur_sleep_s | mean_power_measure_mW | mean_power_send_mW | mean_power_sleep_mW | total_energy_meas_Ws | total_energy_send_Ws | total_energy_sleep_Ws | total_energy_cycle_Ws | cycle_duration_s
1 | 6.5 | 35.9 | 50.3 | 29.4 | 14.5 | 583.8 | 548.2 | 573.2 | 4.4 | 16.1 | 8.3 | 2.6 | 27.0 | 627.6
2 | 634.1 | 664.6 | 679.0 | 30.5 | 14.3 | 582.7 | 566.0 | 608.8 | 4.3 | 17.3 | 8.7 | 2.5 | 28.5 | 627.6
3 | 1261.7 | 1292.0 | 1306.6 | 30.4 | 14.5 | 582.6 | 563.6 | 581.2 | 4.4 | 17.1 | 8.5 | 2.6 | 28.1 | 627.6
4 | 1889.2 | 1918.9 | 1933.0 | 29.7 | 14.1 | 583.8 | 558.8 | 587.5 | 4.3 | 16.6 | 8.3 | 2.5 | 27.4 | 627.6
5 | 2516.8 | 2546.8 | 2561.4 | 30.0 | 14.6 | 0.0 | 552.3 | 644.9 | 0.0 | 16.6 | 9.4 | 0.0 | 25.9 | 44.5

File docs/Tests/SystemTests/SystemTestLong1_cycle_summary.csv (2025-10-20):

cycle | t_start_s | t_send_s | t_end_s | dur_measure_s | dur_send_s | dur_sleep_s | mean_power_measure_mW | mean_power_send_mW | mean_power_sleep_mW | total_energy_meas_Ws | total_energy_send_Ws | total_energy_sleep_Ws | total_energy_cycle_Ws | cycle_duration_s
1 | 3.8 | 48.8 | 60.6 | 45.0 | 11.8 | 314.4 | 477.3 | 511.0 | 4.3 | 21.5 | 6.0 | 1.3 | 28.9 | 371.2
2 | 375.0 | 422.9 | 434.7 | 47.9 | 11.8 | 244.7 | 476.1 | 516.0 | 4.4 | 22.8 | 6.1 | 1.1 | 30.0 | 304.4
3 | 679.4 | 723.1 | 734.0 | 43.7 | 10.9 | 0.0 | 472.8 | 491.4 | 0.0 | 20.7 | 5.4 | 0.0 | 26.0 | 54.6

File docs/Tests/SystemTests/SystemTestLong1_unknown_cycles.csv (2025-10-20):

cycle | t_start_s | t_send_s | t_end_s | dur_measure_s | dur_send_s | dur_sleep_s | mean_power_measure_W | mean_power_send_W | energy_consumed_Wh
4 | 1124.6 | 1124.73 | 1124.73 | 0.13000000000010914 | 0.0 | 0.049999999999954525 | 0.2658175827076923 | 0.03499963 | 2.809999999999792e-06
5 | 1124.78 | 1127.73 | 1127.73 | 2.9500000000000455 | 0.0 | 0.0 | 0.499062873398644 | 0.18856676519999999 | 0.00010223000000000003

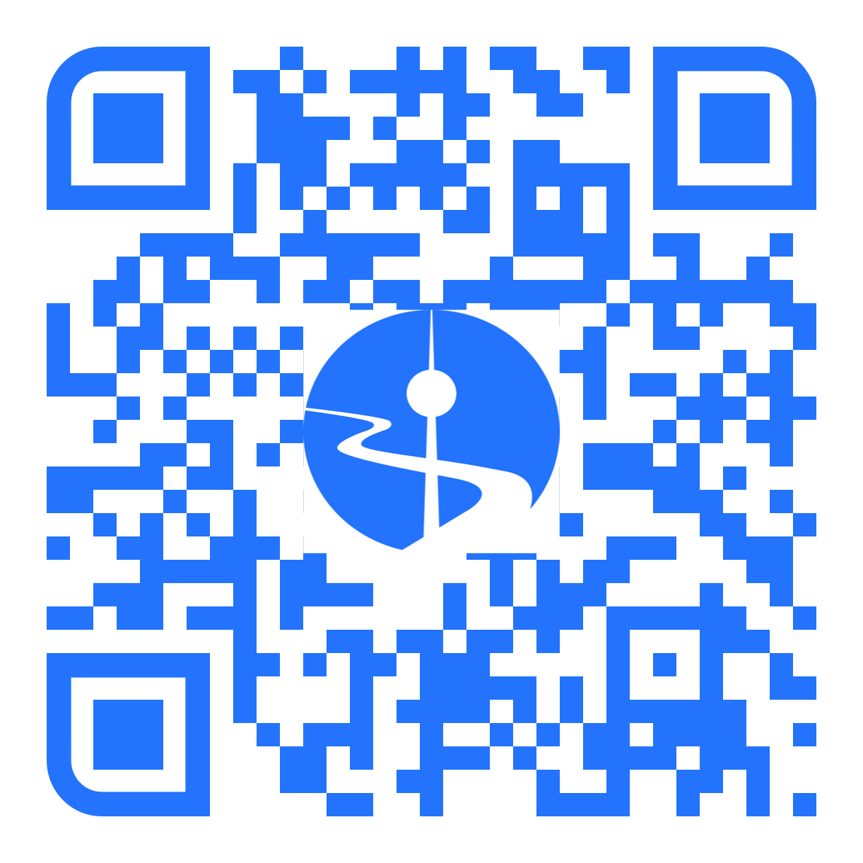
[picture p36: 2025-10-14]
src/ESP_GSM_TEST/images/spreeberlin_qr.png

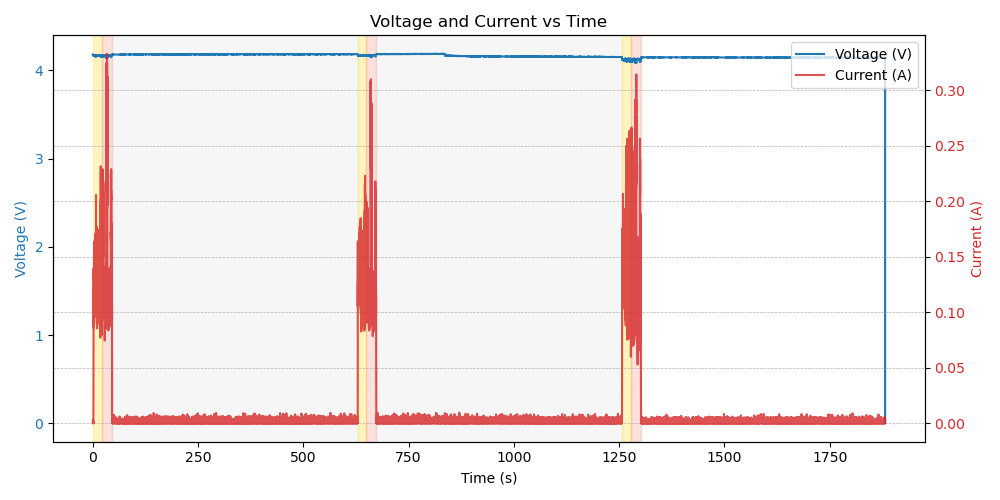
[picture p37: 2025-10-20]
docs/Tests/SystemTests/SystemTestLong2_voltage_current.png

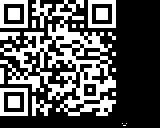
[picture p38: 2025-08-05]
src/ESP_GSM_TEST/images/qr_full.bmp

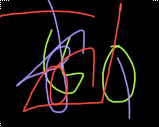
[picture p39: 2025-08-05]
src/ESP_GSM_TEST/images/test1.bmp

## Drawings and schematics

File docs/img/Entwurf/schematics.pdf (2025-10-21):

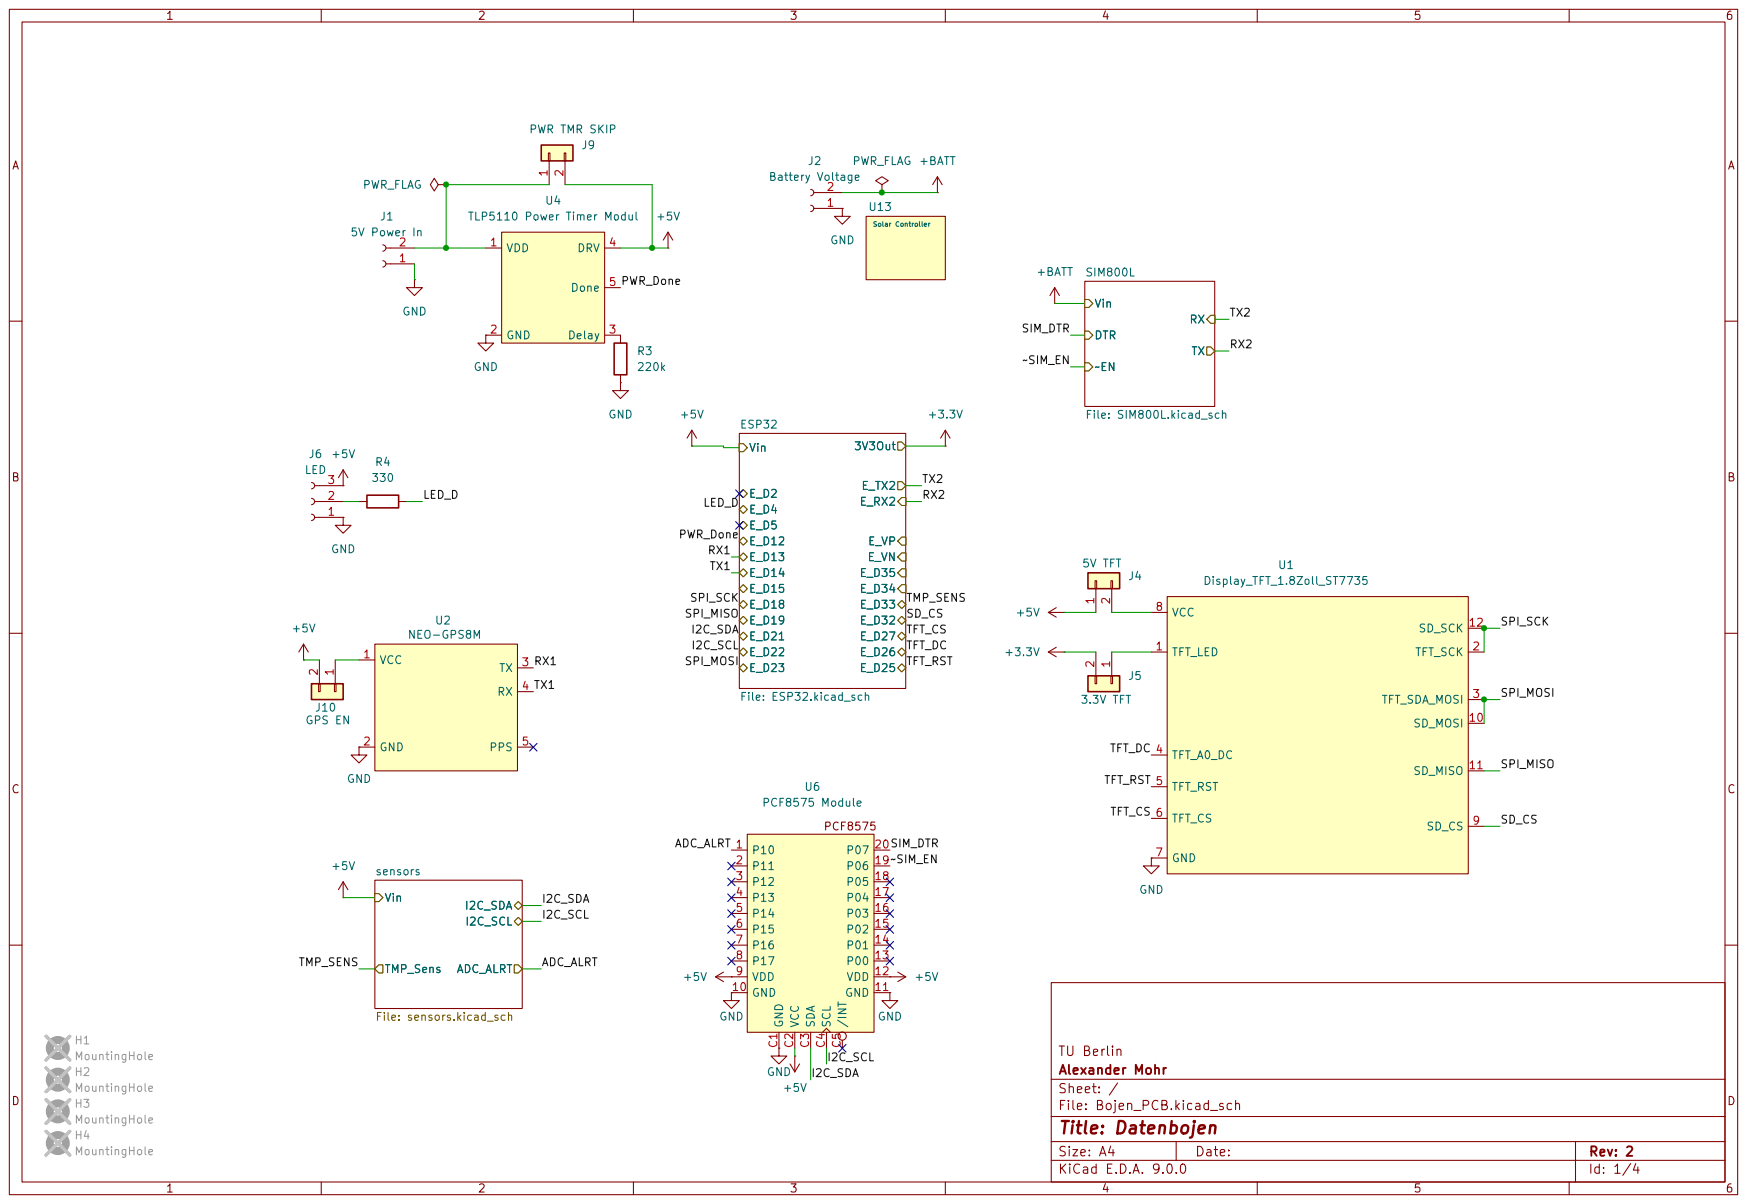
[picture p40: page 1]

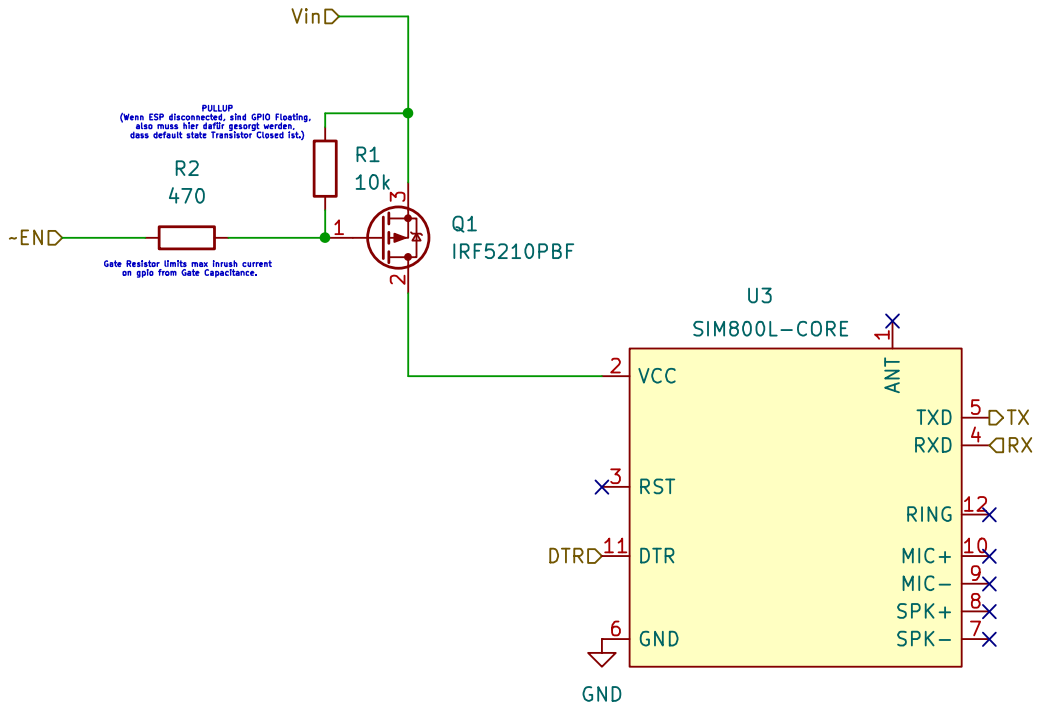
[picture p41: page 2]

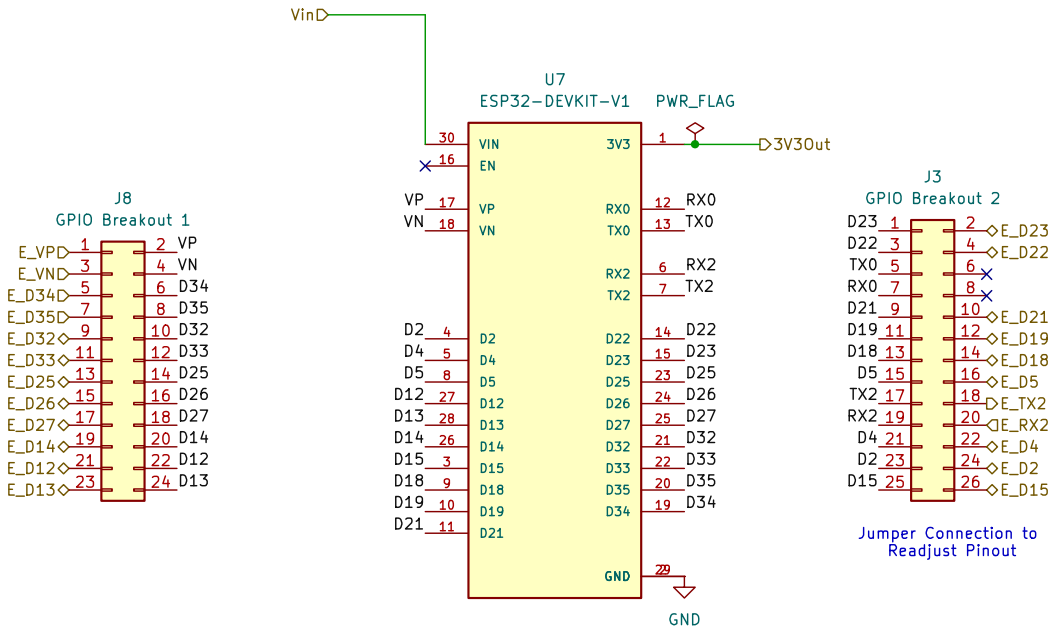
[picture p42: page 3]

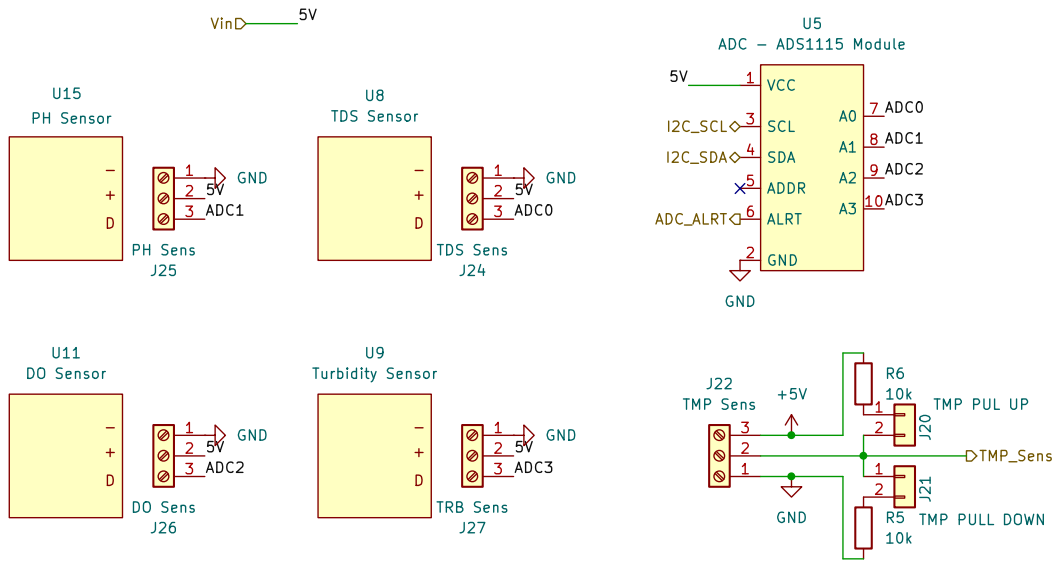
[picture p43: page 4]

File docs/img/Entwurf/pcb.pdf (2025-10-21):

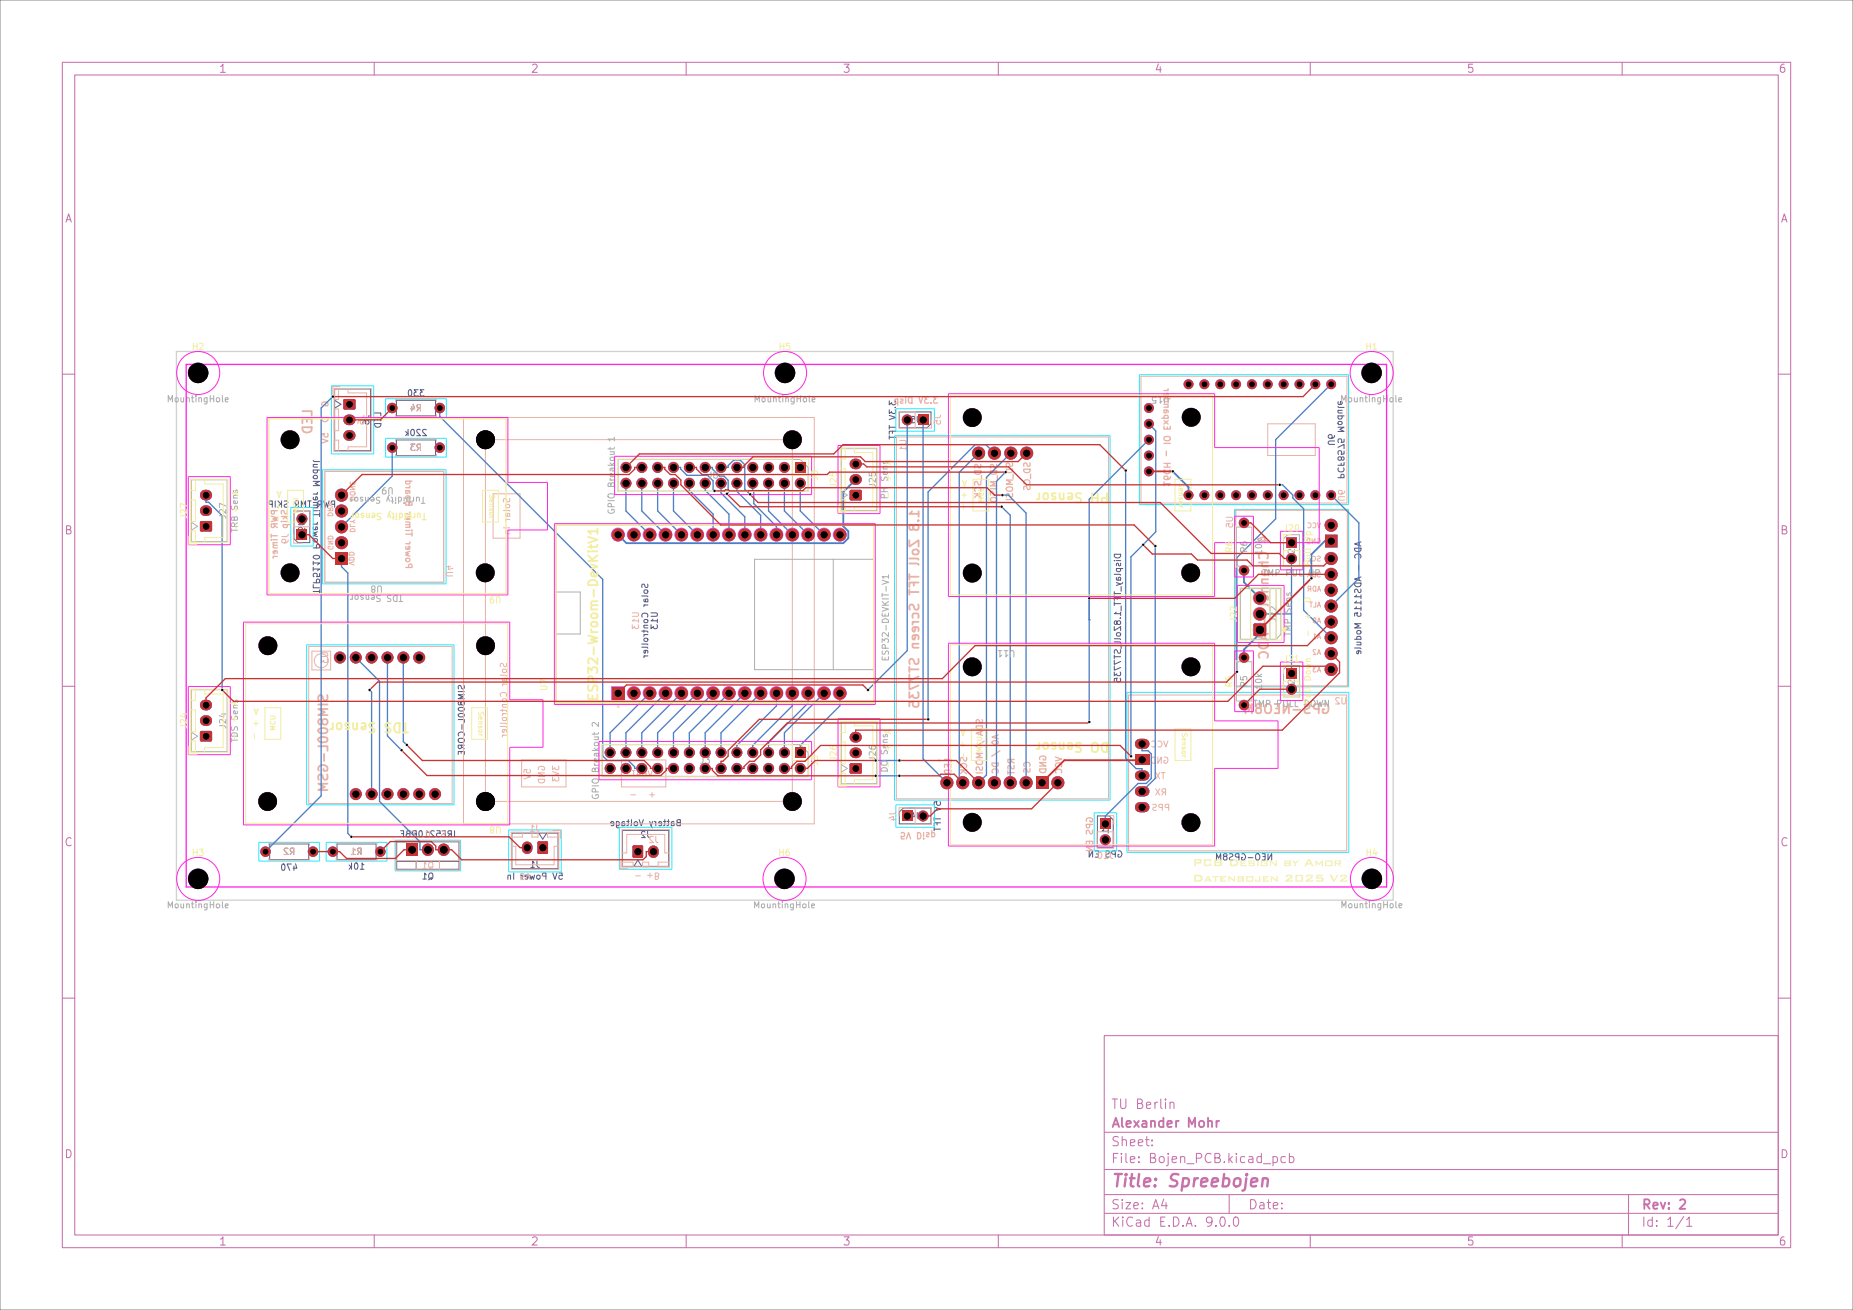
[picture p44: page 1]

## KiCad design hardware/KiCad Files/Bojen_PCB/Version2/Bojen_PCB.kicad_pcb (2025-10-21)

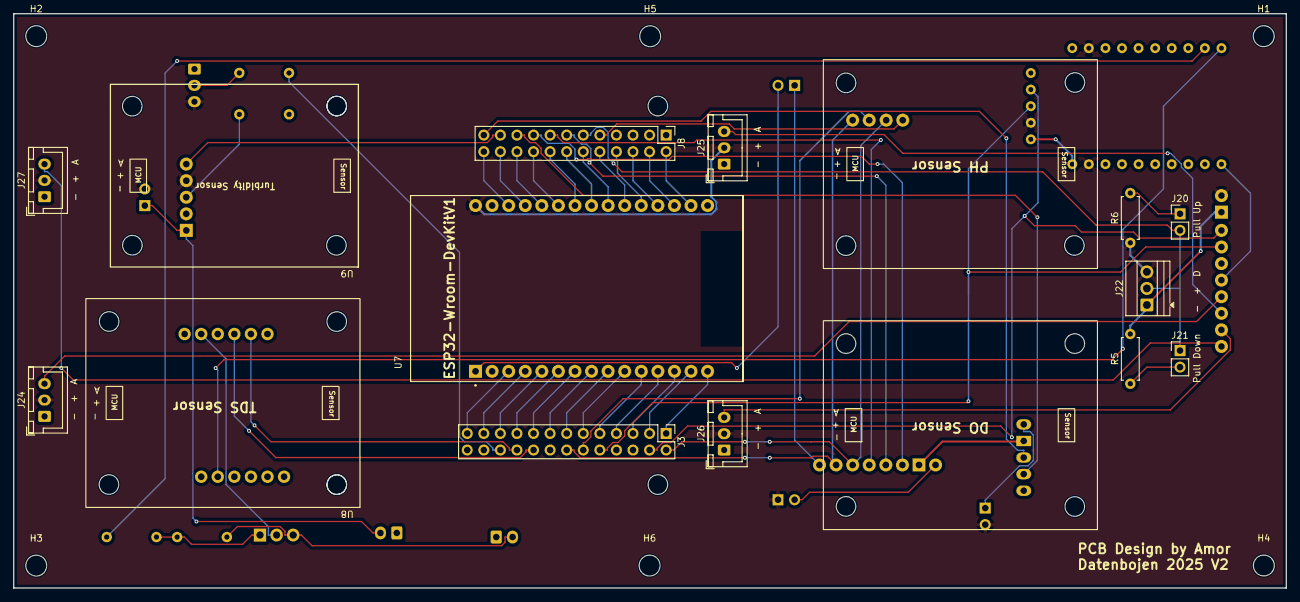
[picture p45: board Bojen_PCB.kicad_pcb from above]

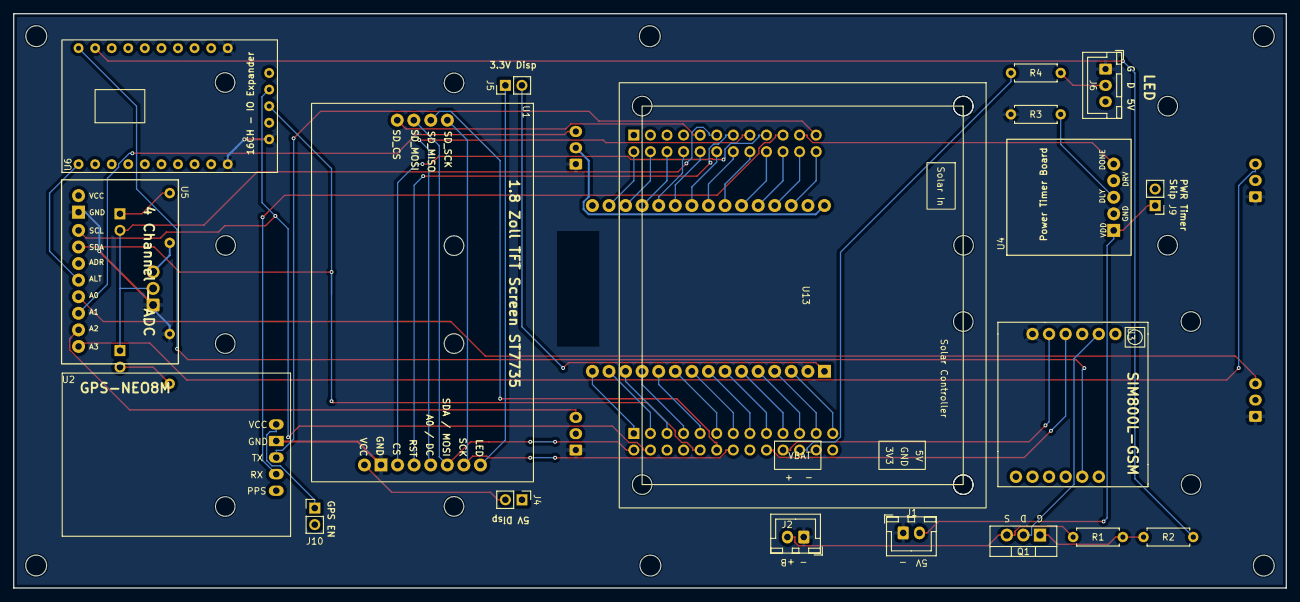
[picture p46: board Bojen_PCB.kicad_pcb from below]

Board: 2 copper layers, 195.0 x 88.0 mm, 41 parts (19 on the bottom side), 62 nets.

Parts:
H1, H2, H3, H4, H5, H6: MountingHole; MountingHole_3.2mm_M3
J1: 5V Power In; JST_XH_B2B-XH-A_1x02_P2.50mm_Vertical
J2: Battery Voltage; JST_XH_B2B-XH-A_1x02_P2.50mm_Vertical
J3: GPIO Breakout 2; PinHeader_2x13_P2.54mm_Vertical
J4: 5V TFT; PinHeader_1x02_P2.54mm_Vertical
J5: 3.3V TFT; PinHeader_1x02_P2.54mm_Vertical
J6: LED; JST_XH_B3B-XH-A_1x03_P2.50mm_Vertical
J8: GPIO Breakout 1; PinHeader_2x12_P2.54mm_Vertical
J9: PWR TMR SKIP; PinHeader_1x02_P2.54mm_Vertical
J10: GPS EN; PinHeader_1x02_P2.54mm_Vertical
J20: TMP PUL UP; PinHeader_1x02_P2.54mm_Vertical
J21: TMP PULL DOWN; PinHeader_1x02_P2.54mm_Vertical
J22: TMP Sens; TerminalBlock_Xinya_XY308-2.54-3P_1x03_P2.54mm_Horizontal
J24: TDS Sens; JST_XH_B3B-XH-A_1x03_P2.50mm_Vertical
J25: PH Sens; JST_XH_B3B-XH-A_1x03_P2.50mm_Vertical
J26: DO Sens; JST_XH_B3B-XH-A_1x03_P2.50mm_Vertical
J27: TRB Sens; JST_XH_B3B-XH-A_1x03_P2.50mm_Vertical
Q1: IRF5210PBF; TO-220-3_Vertical
R1, R5, R6: 10k; R_Axial_DIN0207_L6.3mm_D2.5mm_P7.62mm_Horizontal
R2: 470; R_Axial_DIN0207_L6.3mm_D2.5mm_P7.62mm_Horizontal
R3: 220k; R_Axial_DIN0207_L6.3mm_D2.5mm_P7.62mm_Horizontal
R4: 330; R_Axial_DIN0207_L6.3mm_D2.5mm_P7.62mm_Horizontal
U1: Display_TFT_1.8Zoll_ST7735; ST7735 TFT Screen 1.8 Zoll no hole
U2: NEO-GPS8M; GY-NEO8MV2 no hole
U3: SIM800L-CORE
U4: TLP5110 Power Timer Modul; TPL5110 Board no hole
U5: ADC - ADS1115 Module; ADC - ADS1115 Module no hole
U6: PCF8575 Module; 16-bit IO Expander
U7: ESP32-DEVKIT-V1; MODULE_ESP32_DEVKIT_V1 no hole
U8: TDS Sensor; TDS Sensor DFRobot
U9: Turbidity Sensor; Turbidity Sensor DFRobot
U11: DO Sensor; DO Sensor DFRobot
U13: Solar Controller; Solar Power MPPT Module
U15: PH Sensor; PH Sensor DFRobot

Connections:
+3.3V: J5.2, U7.1 (3V3)
+5V: J4.1, J6.3, J9.2, J10.2, J22.3, J24.2, J25.2, J26.2, J27.2, R6.1, U4.4 (DRV), U5.1 (VCC), U6.9 (VDD), U6.12 (VDD), U6.C2 (VCC), U7.30 (VIN)
+BATT: J2.2, Q1.3 (S), R1.1
/ADC_ALRT: U5.6 (ALRT), U6.1 (P10)
/ESP32/D2: J3.23, U7.4 (D2)
/ESP32/D4: J3.21, U7.5 (D4)
/ESP32/D5: J3.15, U7.8 (D5)
/ESP32/D12: J8.22, U7.27 (D12)
/ESP32/D13: J8.24, U7.28 (D13)
/ESP32/D14: J8.20, U7.26 (D14)
/ESP32/D15: J3.25, U7.3 (D15)
/ESP32/D18: J3.13, U7.9 (D18)
/ESP32/D19: J3.11, U7.10 (D19)
/ESP32/D21: J3.9, U7.11 (D21)
/ESP32/D22: J3.3, U7.14 (D22)
/ESP32/D23: J3.1, U7.15 (D23)
/ESP32/D25: J8.14, U7.23 (D25)
/ESP32/D26: J8.16, U7.24 (D26)
/ESP32/D27: J8.18, U7.25 (D27)
/ESP32/D32: J8.10, U7.21 (D32)
/ESP32/D33: J8.12, U7.22 (D33)
/ESP32/D34: J8.6, U7.19 (D34)
/ESP32/D35: J8.8, U7.20 (D35)
/ESP32/RX0: J3.7, U7.12 (RX0)
/ESP32/RX2: J3.19, U7.6 (RX2)
/ESP32/TX0: J3.5, U7.13 (TX0)
/ESP32/TX2: J3.17, U7.7 (TX2)
/ESP32/VN: J8.4, U7.18 (VN)
/ESP32/VP: J8.2, U7.17 (VP)
/I2C_SCL: J3.4, U5.3 (SCL), U6.C4 (SCL)
/I2C_SDA: J3.10, U5.4 (SDA), U6.C3 (SDA)
/LED_D: J3.22, R4.2
/PWR_Done: J8.21, U4.5 (Done)
/RX1: J8.23, U2.3 (TX)
/RX2: J3.20, U3.5 (TXD)
/SD_CS: J8.9, U1.9 (SD_CS)
/SIM_DTR: U3.11 (DTR), U6.20 (P07)
/SPI_MISO: J3.12, U1.11 (SD_MISO)
/SPI_MOSI: J3.2, U1.3 (TFT_SDA_MOSI), U1.10 (SD_MOSI)
/SPI_SCK: J3.14, U1.2 (TFT_SCK), U1.12 (SD_SCK)
/TFT_CS: J8.17, U1.6 (TFT_CS)
/TFT_DC: J8.15, U1.4 (TFT_A0_DC)
/TFT_RST: J8.13, U1.5 (TFT_RST)
/TMP_SENS: J8.11, J20.2, J21.1, J22.2
/TX1: J8.19, U2.4 (RX)
/TX2: J3.18, U3.4 (RXD)
/sensors/ADC0: J24.3, U5.7 (A0)
/sensors/ADC1: J25.3, U5.8 (A1)
/sensors/ADC2: J26.3, U5.9 (A2)
/sensors/ADC3: J27.3, U5.10 (A3)
/~SIM_EN: R2.1, U6.19 (P06)
GND: J1.1, J2.1, J6.1, J22.1, J24.1, J25.1, J26.1, J27.1, R3.2, R5.2, U1.7 (GND), U2.2 (GND), U3.6 (GND), U4.2 (GND), U5.2 (GND), U6.10 (GND), U6.11 (GND), U6.C1 (GND), U7.2 (GND), U7.29 (GND)
unnamed: J1.2, J9.1, U4.1 (VDD)
unnamed: J4.2, U1.8 (VCC)
unnamed: J5.1, U1.1 (TFT_LED)
unnamed: J6.2, R4.1
unnamed: J10.1, U2.1 (VCC)
unnamed: J20.1, R6.2
unnamed: J21.2, R5.1
unnamed: Q1.2 (D), U3.2 (VCC)
unnamed: Q1.1 (G), R1.2, R2.2
unnamed: R3.1, U4.3 (Delay)

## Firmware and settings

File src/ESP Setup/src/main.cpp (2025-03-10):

// #include <Arduino.h>
// #define TINY_GSM_MODEM_SIM800
// #define TINY_GSM_DEBUG Serial
// #include "TinyGsmClient.h"
// #define SMS_TARGET "015739119874"
// const char apn[] = "internet.v6.telekom";
// // HardwareSerial Serial2(2);
// #define GSM_RX_PIN 16
// #define GSM_TX_PIN 17
// #define GSM_BAUD 9600
// TinyGsm modem(Serial2);

// #define TDS_SENSOR_PIN 12
// #define VREF 3.3          // analog reference voltage(Volt) of the ADC
// #define SCOUNT 30         // sum of sample point
// int analogBuffer[SCOUNT]; // store the analog value in the array, read from ADC
// int analogBufferTemp[SCOUNT];
// int analogBufferIndex = 0, copyIndex = 0;
// float averageVoltage = 0, tdsValue = 0, temperature = 25;

// int getMedianNum(int bArray[], int iFilterLen);

// char ser_buffer[1024];

// void updateSerial()
// {
//   while(Serial2.available()) 
//   {
//     size_t ser_in_size = Serial2.read(ser_buffer,1024);
//     Serial.write(ser_buffer,ser_in_size);//Forward what Software Serial received to Serial Port
//   }
//   while (Serial.available()) 
//   {
//     size_t ser_in_size = Serial.read(ser_buffer,1024);
//     Serial.write(ser_buffer, ser_in_size);
//     Serial2.write(ser_buffer, ser_in_size);//Forward what Serial received to Software Serial Port
//   }
//   delay(2000);
// }

// void sendATCommand(String cmd){
//   Serial.printf("Sending to GSM: %s",cmd);
//   Serial2.println(cmd);
//   updateSerial();
// }

// void test_AT_Raw(){
//   sendATCommand("AT"); //Once the handshake test is successful, it will back to OK
//   sendATCommand("AT+CSQ"); //Signal quality test, value range is 0-31 , 31 is the best
//   sendATCommand("AT+CCID"); //Read SIM information to confirm whether the SIM is plugged
//   sendATCommand("AT+CREG?"); //Check whether it has registered in the network
// }

// void sendSMS(float val)
// {
//   bool res = modem.sendSMS(SMS_TARGET, String("Esp32 Sensor Data: ") + String(val));
//   DBG("SMS:" + res ? "OK" : "fail");
// }


// void sendSMS_RAW(){
//   Serial.println("Sending SMS");
// //List of supported responses
//   sendATCommand("AT+CMGF=?");
  
// //Get the current SMS Mode
// // 0 - PDU Mode, 1- Text Mode,
//   sendATCommand("AT+CMGF?");

// //WAIT for 1 sec
//   // sendATCommand("WAIT=1");

// //Check whether device is registered
// //If device is not registered, SMS cannot be sent
//   sendATCommand("AT+CREG?");

// //First let us send SMS in text mode
//   sendATCommand("AT+CMGF=1");
// // Send the message. Set your To number below
// // Yazdan "016096667146"
//   sendATCommand("AT+CMGS=\"015739119874\"");
//   //Type the SMS text below
//   sendATCommand("Text Message Test from GSM Modul -Alex");
//   Serial2.write(0x1A);
//   delay(2000);


// //Send the CTRL+Z character. ^z is special command of AT Command Script engine.
//   Serial.println("SMS Send");
// }


// void setup_main()
// {
//   Serial.begin(112500);
//   while (!Serial)
//   {
//     delay(10);
//   }
//   Serial2.begin(9600, SERIAL_8N1, GSM_RX_PIN, GSM_TX_PIN);

//   // test_AT_Raw();
//   // sendSMS_RAW();


//   // serial_relay();

//   // S.println("AT");
//   // delay(100);
//   // if (GSM_Serial.available())
//   // {
//   //   Serial.println(GSM_Serial.readString());
//   // }
//   // serial_relay();

//   modem.setBaud(9600);
//   modem.begin();
//   modem.getSimStatus();
//   modem.getModemInfo();
//   // printInfoGSM();
//   // modem.sendAT("AT+CMGF=0");
//   Serial.printf("Connected: %d", modem.isNetworkConnected());
//   modem.sendSMS(SMS_TARGET, "Hello World!");  // Setzt CMGF=1 -> Textmodus


//   // modem.ge("http://www.google.com");''

//   // bool ret = modem.isNetworkConnected();
//   // DBG("Network:", ret ? "Connected" : "Not Connected");
//   // modem.maintain();

//   // Serial.println("Connecting GSM Module");
//   // if (!modem.restart())
//   // {
//   //   Serial.println("Failed to restart modem, delaying 10s and retrying");
//   //   delay(10000);
//   //   esp_restart();
//   // }
//   // Serial.println("GSM Module connected");
//   // sendSMS_RAW();


//   // while (!modem.isNetworkConnected()) {
//   //   Serial.print(F("GSM...."));
//   //   while (!modem.restart()) {
//   //     Serial.print(".");
//   //   }
//   //   Serial.println();

//   //   Serial.print(F("Waiting for network...."));
//   //   if (modem.waitForNetwork() && modem.isNetworkConnected()) {
//   //     Serial.println(F("connected."));
//   //   }
//   //   else {
//   //     Serial.println(F("connection error."));
//   //   }
//   // }
//   // Serial.println("Module Connected to Network");

//   // modem.sendSMS("Hello World!",SMS_TARGET);
//   // modem.gprsConnect(apn);
//   // delay(5000);
//   // if (!modem.isGprsConnected())
//   //   Serial.println("GPRS not Connected!");
//   // sendSMS(1);
//   // pinMode(TDS_SENSOR_PIN, INPUT);
//   while(true){
//     updateSerial();
//   }
// }



// void printInfoGSM(){
  
//   String modemInfo = modem.getModemInfo();
//   DBG("Modem Info:", modemInfo);

//   String name = modem.getModemName();
//   DBG("Modem Name:", name);

//   String manufacturer = modem.getModemManufacturer();
//   DBG("Modem Manufacturer:", manufacturer);

//   String hw_ver = modem.getModemModel();
//   DBG("Modem Hardware Version:", hw_ver);

//   String fv_ver = modem.getModemRevision();
//   DBG("Modem Firware Version:", fv_ver);

//   bool res = modem.isGprsConnected();
//   DBG("GPRS status:", res ? "connected" : "not connected");

//   String ccid = modem.getSimCCID();
//   DBG("CCID:", ccid);

//   String imei = modem.getIMEI();
//   DBG("IMEI:", imei);

//   String imsi = modem.getIMSI();
//   DBG("IMSI:", imsi);

//   String cop = modem.getOperator();
//   DBG("Operator:", cop);

//   String prov = modem.getProvider();
//   DBG("Provider:", prov);

//   IPAddress local = modem.localIP();
//   DBG("Local IP:", local);

//   int csq = modem.getSignalQuality();
//   DBG("Signal quality:", csq);
// }




// void loop_main()
// {
//   static unsigned long analogSampleTimepoint = millis();
//   if (millis() - analogSampleTimepoint > 40U) // every 40 milliseconds,read the analog value from the ADC
//   {
//     analogSampleTimepoint = millis();
//     analogBuffer[analogBufferIndex] = analogRead(TDS_SENSOR_PIN); // read the analog value and store into the buffer
//     analogBufferIndex++;
//     if (analogBufferIndex == SCOUNT)
//       analogBufferIndex = 0;
//   }
//   static unsigned long printTimepoint = millis();
//   if (millis() - printTimepoint > 800U)
//   {
//     printTimepoint = millis();
//     for (copyIndex = 0; copyIndex < SCOUNT; copyIndex++)
//       analogBufferTemp[copyIndex] = analogBuffer[copyIndex];
//     averageVoltage = getMedianNum(analogBufferTemp, SCOUNT) * (float)VREF / 4096.0;                                                                                                  // read the analog value more stable by the median filtering algorithm, and convert to voltage value
//     float compensationCoefficient = 1.0 + 0.02 * (temperature - 25.0);                                                                                                               // temperature compensation formula: fFinalResult(25^C) = fFinalResult(current)/(1.0+0.02*(fTP-25.0));
//     float compensationVolatge = averageVoltage / compensationCoefficient;                                                                                                            // temperature compensation
//     tdsValue = (133.42 * compensationVolatge * compensationVolatge * compensationVolatge - 255.86 * compensationVolatge * compensationVolatge + 857.39 * compensationVolatge) * 0.5; // convert voltage value to tds value
//     // Serial.print("voltage:");
//     // Serial.print(averageVoltage,2);
//     // Serial.print("V   ");
//     Serial.print("TDS Value:");
//     Serial.print(tdsValue, 0);
//     Serial.println("ppm");
//     if (tdsValue > 20){
//       sendSMS(tdsValue);
//     }
//   }
// }

// int getMedianNum(int bArray[], int iFilterLen)
// {
//   int bTab[iFilterLen];
//   for (byte i = 0; i < iFilterLen; i++)
//     bTab[i] = bArray[i];
//   int i, j, bTemp;
//   for (j = 0; j < iFilterLen - 1; j++)
//   {
//     for (i = 0; i < iFilterLen - j - 1; i++)
//     {
//       if (bTab[i] > bTab[i + 1])
//       {
//         bTemp = bTab[i];
//         bTab[i] = bTab[i + 1];
//         bTab[i + 1] = bTemp;
//       }
//     }
//   }
//   if ((iFilterLen & 1) > 0)
//     bTemp = bTab[(iFilterLen - 1) / 2];
//   else
//     bTemp = (bTab[iFilterLen / 2] + bTab[iFilterLen / 2 - 1]) / 2;
//   return bTemp;
// }

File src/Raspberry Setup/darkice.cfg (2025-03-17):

[general]
duration = 0 # Stream indefinitely
bufferSecs = 5 # Buffer for the input, in seconds
reconnect = yes # Reconnect to the server if disconnected

[input]
device = default # Your audio capture device
sampleRate = 44100 # Sample rate in Hz
bitsPerSample = 16 # Bits per sample
channel = 2 # 2 = stereo, 1 = mono

[icecast2-0]
bitrateMode = cbr # Constant bit rate
format = mp3 # Audio format
bitrate = 128 # Bitrate in kbps
server = localhost # Server name or IP
port = 8000 # Port number
password = 55555 # Your Icecast password
mountPoint = audio_stream # Mount point to stream to
name = # Name of the stream
description = # Description of the stream
url = # URL related to the stream
genre = # Genre of the stream
public = no # Do not list on public lists

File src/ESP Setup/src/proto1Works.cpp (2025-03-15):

#define TINY_GSM_MODEM_SIM800
#define TINY_GSM_DEBUG Serial
#include "TinyGsmClient.h"
#include "yazdan_code.h"

#include <ArduinoJson.h>

#include <FastLED.h>

#define SerialMon Serial
#define SerialAT Serial2

#define GSM_RX_PIN 16
#define GSM_TX_PIN 17

// const char apn[]  = "internet.telekom"; // APN for your GSM network
// const char user[] = "telekom";         // User for APN, if required
// const char pass[] = "tm";         // Password for APN, if required

const char server[] = "http://jserv.ddns.net:8080";

#define SMS_TARGET "+4915739119874"
#define SMS_TARGET2 "+4916091253550"

#define PIXEL_PIN 32
#define NUM_LEDS 1
#define BRIGHTNESS 50

CRGB leds[NUM_LEDS];

TinyGsm modem(SerialAT);
TinyGsmClient client(modem);

#define SERIAL_RELAY_BUFFER_SIZE 1024
char ser_buffer[SERIAL_RELAY_BUFFER_SIZE];
int manual_at_mode = 0;

void printGSMNetworkStatus()
{
    Serial.printf("GSM Module Status:\n");
    Serial.printf("Connected: %d\n", modem.isNetworkConnected());
    Serial.printf("GPRS: %d\n", modem.isGprsConnected());
    Serial.printf("Signal strength: %d\n", modem.getSignalQuality());
}

void printBattStatus()
{
    int8_t chargeState, percent;
    int16_t milliVolts;
    modem.getBattStats(chargeState, percent, milliVolts);
    Serial.printf("Battery level: %d%%\n", percent);
    Serial.printf("Battery voltage: %dmV\n", milliVolts);
    Serial.printf("Battery charging: %d\n", chargeState);
}

void led_update()
{
    // Turn the LED on, then pause
    leds[0] = CRGB::Red;
    FastLED.show();
    delay(500);
    // Now turn the LED off, then pause
    leds[0] = CRGB::Black;
    FastLED.show();
    delay(500);
}

void play_startup_Led_Blink()
{
    pinMode(LED_BUILTIN, OUTPUT);
    digitalWrite(LED_BUILTIN, HIGH);
    delay(100);
    digitalWrite(LED_BUILTIN, LOW);
    delay(500);
    digitalWrite(LED_BUILTIN, HIGH);
    delay(100);
    digitalWrite(LED_BUILTIN, LOW);
    delay(500);
    digitalWrite(LED_BUILTIN, HIGH);
    delay(100);
    digitalWrite(LED_BUILTIN, LOW);
    delay(500);
}

void init_leds()
{
    Serial.println("Initializing LED strip...");
    FastLED.addLeds<WS2812B, PIXEL_PIN, GRB>(leds, NUM_LEDS); // GRB ordering is typical
    FastLED.setBrightness(BRIGHTNESS);

    led_update();
    led_update();
    led_update();
    led_update();
}

void init_modem()
{
    SerialMon.println("Initializing modem...");
    // Set GSM module baud rate
    SerialAT.begin(9600, SERIAL_8N1, GSM_RX_PIN, GSM_TX_PIN);
    delay(3000);

    modem.setBaud(9600);
    modem.begin();
    modem.getSimStatus();
    modem.getModemInfo();
    // printInfoGSM();
    // modem.sendAT("AT+CMGF=0");
    Serial.printf("Connected: %d\n", modem.isNetworkConnected());
}

void init_serial()
{
    // Set console baud rate
    SerialMon.begin(115200);
    delay(1000);
}

void setup()
{
    play_startup_Led_Blink();

    init_serial();

    init_leds();

    init_modem();

    sensors_init();
}

void updateSerial()
{
    while (SerialAT.available())
    {
        size_t ser_in_size = SerialAT.read(ser_buffer, SERIAL_RELAY_BUFFER_SIZE);
        Serial.print("GSM: ");
        Serial.write(ser_buffer, ser_in_size); // Forward what Software Serial received to Serial Port
    }
    while (Serial.available())
    {
        size_t ser_in_size = Serial.read(ser_buffer, SERIAL_RELAY_BUFFER_SIZE);
        Serial.print("Send to GSM: ");
        Serial.write(ser_buffer, ser_in_size);
        SerialAT.write(ser_buffer, ser_in_size); // Forward what Serial received to Software Serial Port
    }
    delay(2000);
}

void handleSerial()
{
    if (Serial.available())
    {
        char a = Serial.peek();
        if (a == 's')
        {
            manual_at_mode = !manual_at_mode;
            Serial.printf("Manual AT mode: %d\n", manual_at_mode);
        }
    }
    updateSerial();
}

int echo_gms_cmds = 1;

void sendCmd(const char *cmd)
{
    if (echo_gms_cmds)
    {
        Serial.print("Send to GSM: ");
        Serial.println(cmd);
        // Serial.flush();
    }
    SerialAT.println(cmd);
    SerialAT.flush();
    delay(1000);
}

/**
 * 1  Error
 * 0 OK
 *
 *  */
int waitForResp(const char *resp, unsigned int timeout)
{
    int len = strlen(resp);
    int sum = 0;
    unsigned long timerStart, timerEnd;
    timerStart = millis();

    while (1)
    {
        if (SerialAT.available())
        {
            char c = SerialAT.read();
            Serial.print(c);
            sum = (c == resp[sum] || resp[sum] == 'X') ? sum + 1 : 0;
            if (sum == len)
                break;
        }
        timerEnd = millis();
        if (timerEnd - timerStart > timeout)
        {
            return 1;
        }
    }

    while (SerialAT.available())
    {
        SerialAT.read();
    }

    Serial.println();

    return 0;
}

int sendCmdAndWaitForResp(const char *cmd, const char *resp, unsigned timeout)
{
    sendCmd(cmd);
    return waitForResp(resp, timeout);
}

void send_sms_data()
{
    int status = modem.sendSMS(SMS_TARGET2, "Temp: " + String(readTemperature())); // Setzt CMGF=1 -> Textmodus
    Serial.printf("SMS sent: %s\n", status ? "OK" : "fail");
}

void gsm_send_serial(String cmd)
{
    Serial.println(cmd);
    SerialAT.println(cmd);
    delay(1000);
    updateSerial();
}

#define STD_WAIT_TIME 4000

void end_http()
{
    sendCmdAndWaitForResp("AT+HTTPTERM", "OK", STD_WAIT_TIME);
    sendCmdAndWaitForResp("AT+SAPBR=0,1", "OK", STD_WAIT_TIME);
}

int send_network_data()
{
    Serial.println(" --- Start GPRS & HTTP --- ");

    float temp = readTemperature();
    char data[100];
    int len = snprintf(data, 100, "{\"temp\":\"%f\"}", temp);
    int resp = 0;
    resp += sendCmdAndWaitForResp("AT+CREG?", "+CREG: 0,5", STD_WAIT_TIME);
    resp += sendCmdAndWaitForResp("AT+SAPBR=1,1", "OK", STD_WAIT_TIME);
    resp += sendCmdAndWaitForResp("AT+SAPBR=2,1", "+SAPBR: 1,1,\"X.X.X.X\"", STD_WAIT_TIME);
    resp += sendCmdAndWaitForResp("AT+SAPBR=4,1", "OK", STD_WAIT_TIME);
    resp += sendCmdAndWaitForResp("AT+HTTPINIT", "OK", STD_WAIT_TIME);
    resp += sendCmdAndWaitForResp("AT+HTTPPARA=CID,1", "OK", STD_WAIT_TIME);
    resp += sendCmdAndWaitForResp("AT+HTTPPARA=URL,http://jserv.ddns.net:8080", "OK", STD_WAIT_TIME);
    resp += sendCmdAndWaitForResp("AT+HTTPPARA=CONTENT,application/json", "OK", STD_WAIT_TIME);
    resp += sendCmdAndWaitForResp("AT+HTTPDATA=100,5000", "DOWNLOAD", STD_WAIT_TIME);
    resp += sendCmdAndWaitForResp(data, "OK", STD_WAIT_TIME);
    resp += sendCmdAndWaitForResp("AT+HTTPACTION=1", "+HTTPACTION: 1,200", STD_WAIT_TIME);
    resp += sendCmdAndWaitForResp("AT+HTTPREAD", "OK", STD_WAIT_TIME);
    resp += sendCmdAndWaitForResp("AT+HTTPTERM", "OK", STD_WAIT_TIME);
    resp += sendCmdAndWaitForResp("AT+SAPBR=0,1", "OK", STD_WAIT_TIME);

    // TODO: Angeben ob Response Compare erfolgreich, und response gut formatiert ausgeben

    // if (resp)
    //     end_http();
    return resp;
}
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

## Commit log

2025-03-15 leds and http self at
2025-03-17 Raspberry Config
    [darkice.cfg]
2025-05-12 Lilly Board Repo geadded
    [1.stl, 2.stl, T-Call-V1.4.dwg]
2025-05-20 httppara text plain und Readme Lillypad Pinout
2025-05-22 Kicad Initial
    [Bojen_PCB.kicad_pcb, Bojen_PCB.kicad_sch, GY-NEO6MV2-withAnt v7.step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]
2025-05-23 PCB Design
    [16Bit I2C ADC+PGA - ADS1115.stp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]
2025-05-24 PCB V2
    [Bojen_PCB-B_Cu.gbr, Bojen_PCB-B_Mask.gbr, Bojen_PCB-B_Paste.gbr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]
2025-05-24 PCB V2 rearange fit tube
    [Bojen_PCB-B_Cu.gbr, Bojen_PCB-B_Mask.gbr, Bojen_PCB-B_Paste.gbr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]
2025-06-05 esp auf pcb
2025-06-27 Feedback PCB
2025-06-27 ADS1115 ADC
2025-07-12 PCB Sensor Code complete Refactor, and TFT Screen Sensor Value Display
2025-08-05 tft Screen QR Code Display
    [Bojen_PCB.kicad_pcb, SIM800L.kicad_sch]
2025-08-06 led module
2025-08-19 Solar Plot Code
    [Bojen_PCB.kicad_pcb]
2025-09-10 QR code update, LED integration, Example Visual Data,
2025-09-13 PCB Updated, Fixes
    [Bojen_PCB.kicad_pcb, Bojen_PCB.kicad_sch, SIM800L.kicad_sch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]
2025-09-16 Exhibition lights for led_module (unfinished)
2025-09-26 Display Fix, led_module cleanup
    [main.cpp]
2025-09-26 led_module back to one in ten
2025-09-26 Final Exhibition anim, debug tft print
2025-10-09 PCB Fixes
    [Bojen_PCB.kicad_sch, SIM800L.kicad_sch]
2025-10-09 LoRa, Timer, GPIO, Wifi
2025-10-09 Lora, Led Test
    [received_data.csv]
2025-10-16 System Schematics
2025-10-20 Python Server Data Plot
    [received_data.csv, received_data_old.csv, received_data_tmp.csv]
2025-10-20 python server Rename, pcb Feedback
    [received_data.csv]
2025-10-20 testCode, images, SystemTestPlot
    [Bojen_PCB.kicad_pcb, Bojen_PCB.kicad_sch, ESP32.kicad_sch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]
2025-10-21 state_module, Bilder
    [Bojen_PCB.kicad_pcb, Bojen_PCB.kicad_sch, ESP32.kicad_sch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]
2025-11-17 Bachelor Work
    [received_data copy.csv, received_data.csv, received_data_adjusted.csv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]
